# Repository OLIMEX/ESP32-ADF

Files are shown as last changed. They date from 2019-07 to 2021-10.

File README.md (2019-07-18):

# ESP32-ADF
ESP32 Audio Development Framework development board

[ESP32-ADF product page](https://www.olimex.com/Products/IoT/ESP32/ESP32-ADF/)

# ESP32-ADF board has these features:
- ESP32-WROVER-B module with 8MB PSRAM, 4MB Flash
- Stereo codec and Audio Amplifier 2x3W
- Stereo Microphones
- Audio out 3.5mm jack
- UEXT connector for sensors and LCDs
- Lipo battery charger
- USB connector and programmer
- Four touch buttons, 3 tactile buttons
- power supply Jack for +5V 1A

# License
- Hardware is with CERN OHL v1.2 license
- Software is with GPL3 license
- Documentation is with CC BY-SA 4.0 license

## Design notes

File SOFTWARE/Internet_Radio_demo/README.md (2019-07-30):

# Play HTTP aac Living stream

The demo plays a m3u downloaded from HTTP. 

## Compatibility

ESP32-ADF
https://www.olimex.com/Products/IoT/ESP32/ESP32-ADF/open-source-hardware

## Usage

Prepare the audio board:

- Connect speakers or headphones to the board.

# Get ESP-ADF
```bash
cd ~/
git clone --recursive https://github.com/espressif/esp-adf.git
cd esp-adf
git submodule update --init
export ADF_PATH=~/esp-adf
```

Load the example:
```bash
git clone https://github.com/d3v1c3nv11/internet_radio_demo.git
cd internet_radio_demo
make menuconfig
```
Configure the example:

- Set up the Wi-Fi connection by running `menuconfig` > `Example Configuration` and filling in `WiFi SSID` and `WiFi Password`.

Run the example:

```bash
make flash monitor
```
- The audio board will first connect to the Wi-Fi.
- Then the board will start playing automatically.
```bash
Use Touch buttons:
Volume: Vol- Vol+
Next station: <Play>
Presset station: <Set>
```

Note: Patch is required to es8388 driver in esp-adf to enable speakers. From project directory run
```bash
patch $ADF_PATH/components/audio_hal/driver/es8388/es8388.c < es8388_fix_speaker_volume.patch 
```
Graphical part of project is based on loboris/ESP32_TFT_library https://github.com/loboris/ESP32_TFT_library

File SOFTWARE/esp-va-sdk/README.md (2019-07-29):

## Overview

The ESP-Voice-Assistant SDK provides an implementation of Amazon's Alexa Voice Service, Google Voice Assistant and Google's conversational interface (aka Dialogflow) for ESP32 microcontroller. This facilitates the developers to evaluate ESP32 based voice assistant/s integrated devices like speakers and other IoT devices. Please refer to [Changelog](CHANGELOG.md) to track release changes and known-issues.

## License
* For LyratD-DSPG board based on DSPG's DBMD5P DSP please read the licensing terms [here](board_support_pkgs/lyratd_dspg/dspg_fw/docs/license.pdf) for the DSP fimrware
* For rest of the ESP-VA-SDK components please refer to the licensing terms [here](LICENSE)

### About SDK

The SDK contains pre-built libraries for Amazon Alexa, Google Voice Assistant (GVA) and Google Dialogflow along with sources of some of the utility components such as audio pipeline and connection manager. Below are the list of some of the features supported for each voice assistant:
* **Amazon Alexa**:
    * Basic conversation
    * Multi-turn conversations
    * Audio Streaming and Playback
    * Audio Book Support: Kindle, Audible
    * Volume control via voice command
    * Seek support for Audible
    * Alarms, Timers, Reminders, Notifications

* **Google Voice Assistant**:
    * Basic conversation
    * Multi-turn conversations
    * Getting weather reports
    * Multiple language support

* **Google Dialogflow**:
    * Basic conversation
    * Multi-turn conversations
    * Configure and control connected devices via voice, e.g "Start the Laundry"
    * Multiple language support

## Supported Hardware

The SDK supports the following hardware platforms:
* [ESP32-LyraT](https://www.espressif.com/en/products/hardware/esp32-lyrat)
* [ESP32-LyraTD-MSC](https://www.espressif.com/en/products/hardware/esp32-lyratd-msc)
* [Olimex ESP32-ADF](https://www.olimex.com/Products/IoT/ESP32/ESP32-ADF/open-source-hardware)

The following list of acoustic front-ends is also supported. Please contact Espressif to enable acccess to these solutions.
* DSPG DBMD5P
* Intel s1000
* Synaptics CX20921

## Getting started

* Follow the `README-Getting-Started.md` to clone the required repositories and to compile and flash the firmware.
* When flashing the SDK for the first time, it is recommended to do `make erase_flash` to wipe out entire flash and start out fresh.
* Go through `README-<voice_assistant>.md` in their respective directories to know how to provision the device and to get authentication tokens from the respective authorization server and flash them onto the device.
* If you are updating from previous release, please check the `Upgrading from Previous Release` section from `README-Getting-Started.md` to know about any specific actions that needs to be taken while upgrading.

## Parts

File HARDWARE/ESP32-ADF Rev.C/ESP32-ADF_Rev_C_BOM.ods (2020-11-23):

Designation | Quantity | Designator | Package
SMD РЕЗ 0603 1.1 K 1% | 1 | R20 | R_0603_5MIL_DWS
SMD КОНД 0603 100 NF Y5V 50VDC 20% | 2 | C13, C24 | C_0603_5MIL_DWS
100nF/50V/20%/Y5V | 3 | C37,C38, C34 | C_0402_5MIL_DWS
SMD РЕЗ 0402 10 K 5% | 8 | R3,R22,R23,R30,R31,R32,R44,R45 | R_0402_5MIL_DWS
SMD КОНД 0603 10 UF 6.3V | 8 | C8,C9,C10,C11,C12,C18,C25,C26 | C_0603_5MIL_DWS
SMD РЕЗ 0402 1 K 5% | 8 | R8,R5,R7,R28,R29,R24,R41,R42 | R_0402_5MIL_DWS
1N5819S4(SOD-123) | 1 | D5 | SOD-123_1C-2A_KA
1N5822/SS34/SMA | 2 | D4,D6 | SMA-KA
SMD КОНД 0603 1 UF 10V X5R | 5 | C19,C20,C27,C28,C29 | C_0603_5MIL_DWS
SMD РЕЗ 0402 2.2 K 5% | 8 | R4,R13,R15,R18,R21,R26,R27,R43 | R_0402_5MIL_DWS
2.2uH/1.5A/DCR<0.1R/CD32 | 1 | L2 | CD32
SMD КОНД 0402 270 PF 50V C0G | 4 | C30,C32,C35,C36 | C_0402_5MIL_DWS
SMD РЕЗ 0402 220 OHM 5% | 7 | R1,R6,R14,R33,R35,R37,R40 | R_0402_5MIL_DWS
SMD РЕЗ 0402 22 OHM 5% | 1 | R11 | R_0402_5MIL_DWS
22uF/6.3V/20%/X5R/C0603 | 4 | C5,C6,C7,C23 | C_0603_5MIL_DWS
SMD РЕЗ 0402 27 K 5% | 1 | R25 | R_0402_5MIL_DWS
27pF/50V/5%/C0G | 2 | C21,C22 | C_0603_5MIL_DWS
SMD РЕЗ 0402 4.7 OHM 1% | 1 | R16 | R_0402_5MIL_DWS
4.99k/1%/R0603 | 1 | R19 | R_0603_5MIL_DWS
SMD КОНД 0805 47 UF 6.3V 20% | 11 | C1,C2,C3,C4,C14,C15,C16,C17,C31,C33,C39 | C_0805_5MIL_DWS
SMD РЕЗ 0402 510 OHM 5% | 4 | R34,R36,R38,R39 | R_0402_5MIL_DWS
AP1231-33 | 1 | U1 | SOT-23-5
BAT54C(SOT23-3) | 1 | U10 | SOT23
BC817-40(SOT23) | 2 | Q4,Q5 | SOT23
SMD СЪЕДИНИТЕЛ B-V-10-LF (GBH254SMT-10) | 1 | UEXT1 | GBH-254-SMT-10_Smaller
BL4054B-42TPRN(SOT23-5) | 1 | U4 | SOT-23-5
CH340T(SSOP20W) | 1 | U5 | SSOP-20W
DTC114YKA | 1 | Q1 | SOT23
DW02R | 3 | BAT1,LSPK1,RSPK1 | LIPO_BAT-CON2DW02R
ES8388(QFN28) | 1 | U6 | QFN28_EP(29)_4.076x4.076x0.9mm_Pitch_0.45mm
ESP32-WROVER-4MB | 1 | U3 | ESP32-WROVER_MODULE_
FB0805/600R/2A | 5 | FB1,FB2,FB3,FB4, L1 | L_0805_5MIL_DWS
LED/GREEN/0603 | 1 | COMPLETE2 | LED_0603_KA
LED/RED/0603 | 1 | PWRLED1 | LED_0603_KA
LED/YELLOW/0603 | 1 | CHARGING1 | LED_0603_KA
microphone10mm | 2 | MIC1,MIC2 | MIC
MISB-SWMM-5B-LF(USB_MICRO) | 1 | USB-UART1 | USB-MICRO_MISB-SWMM-5B_LF
СМД ИС PAM8003 | 1 | U7 | SO-16
PJ-W47S-05D2-LF_V2 | 1 | AUDIO_JACK_5PIN1 | PJ-W47S-05D2-LF_5PIN_V2
PWRJ-2mm(YDJ-1134) | 1 | PWR1 | PWRJ-2mm(YDJ-1136)
SMD РЕЗ. КВАРЦ 3.2 х 2.5 мм 12 MHz 10ppm 20pF | 1 | Y1 | TSX-3.2x2.5mm_GND(3)
RA1206_(4x0603)_4B8_22R | 1 | RM1 | RA1206_(4X0603)_4B8_mine_1.1
RPM7236-H8 | 1 | U8 | RPM7236-H8
SMBJ6.0A(DO-214AA) | 1 | D2 | DO214AA_1(K)-2(A)
SY8089AAAC(SOT23-5) | 1 | U2 | SOT-23-5
T1107A(6x3,8x2,5MM) | 3 | RST1,BUT1,BUT2 | T1107A(6x3,8x2,5MM)
WPM2015-3/TR | 2 | FET1,FET2 | SOT23
SPEAKER S3W402 (3W 4OHM) | 2
BATTERY CABLE | 2

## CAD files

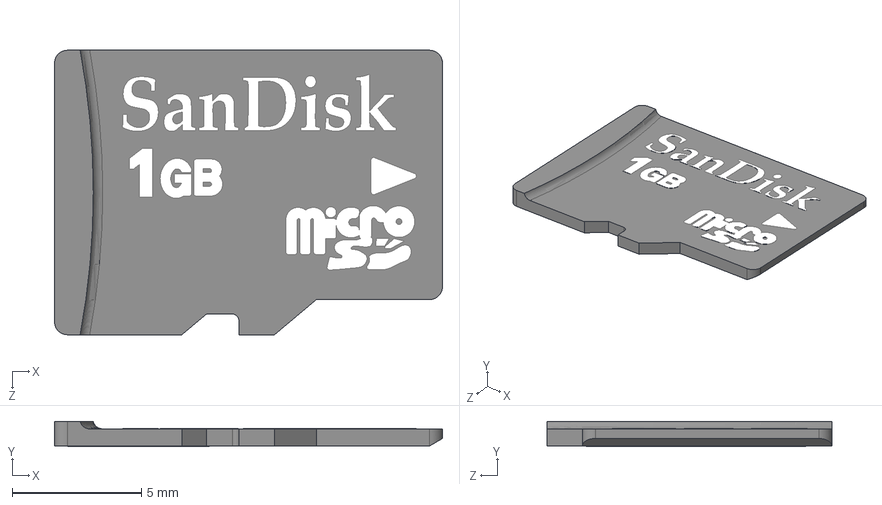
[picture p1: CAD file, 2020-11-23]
HARDWARE/ESP32-ADF Rev.C/3d/Micro_SD_card.step
15.0 x 0.975 x 11.0 mm

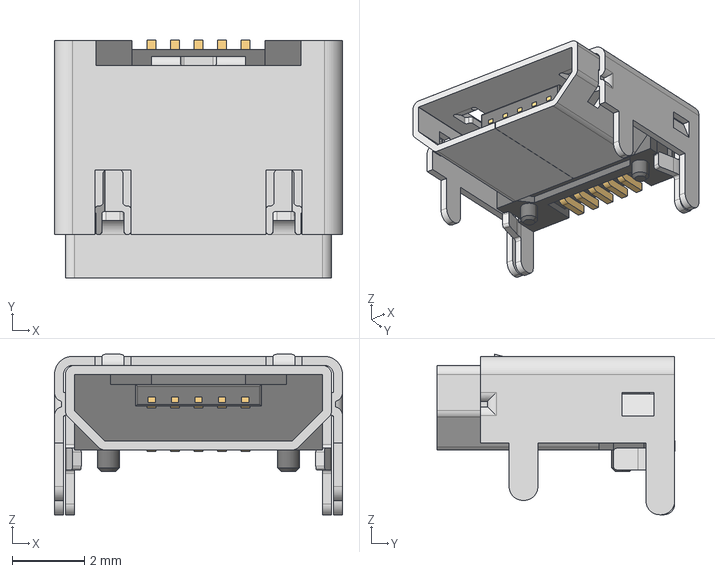
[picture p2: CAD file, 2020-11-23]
HARDWARE/ESP32-ADF Rev.C/3d/usb_micro_4p.stp
8.00 x 6.60 x 4.46 mm

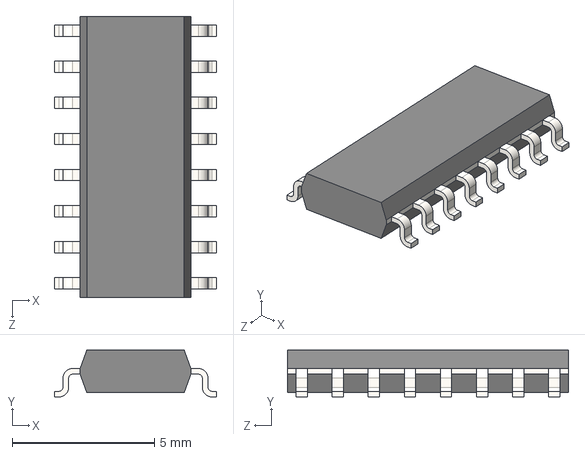
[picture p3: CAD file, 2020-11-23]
HARDWARE/ESP32-ADF Rev.C/3d/SL16.step
5.70 x 1.65 x 9.90 mm

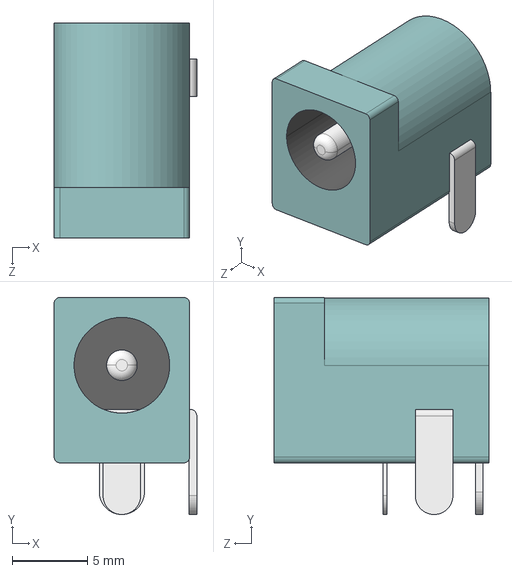
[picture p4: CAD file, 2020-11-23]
HARDWARE/ESP32-ADF Rev.C/3d/User_Library-RAPC722_Power_Jack.step
9.47 x 14.4 x 14.2 mm

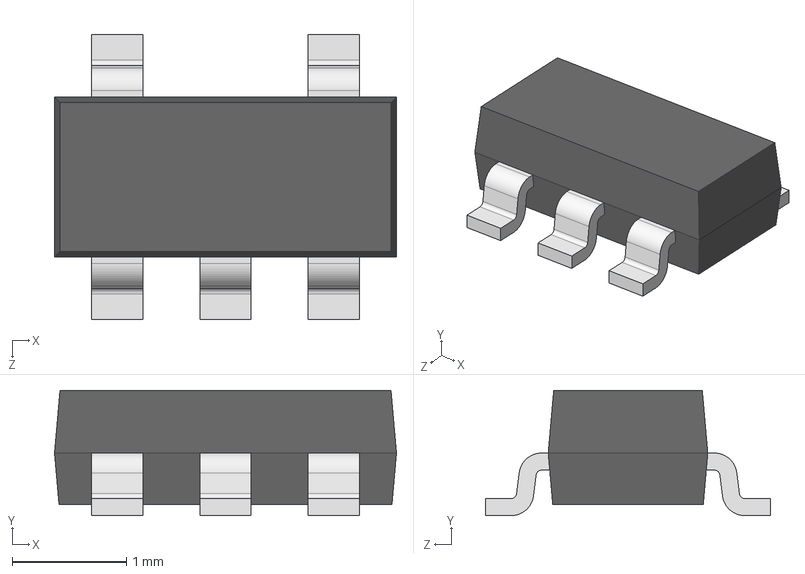
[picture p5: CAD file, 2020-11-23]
HARDWARE/ESP32-ADF Rev.C/3d/SOT-23-5.step
3.00 x 1.10 x 2.50 mm

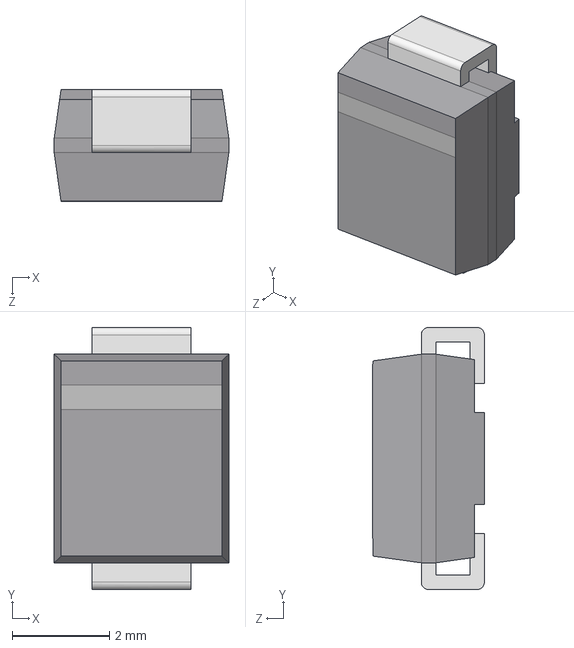
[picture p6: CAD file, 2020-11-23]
HARDWARE/ESP32-ADF Rev.C/3d/DO-214AA_SMB.step
3.60 x 5.40 x 2.30 mm

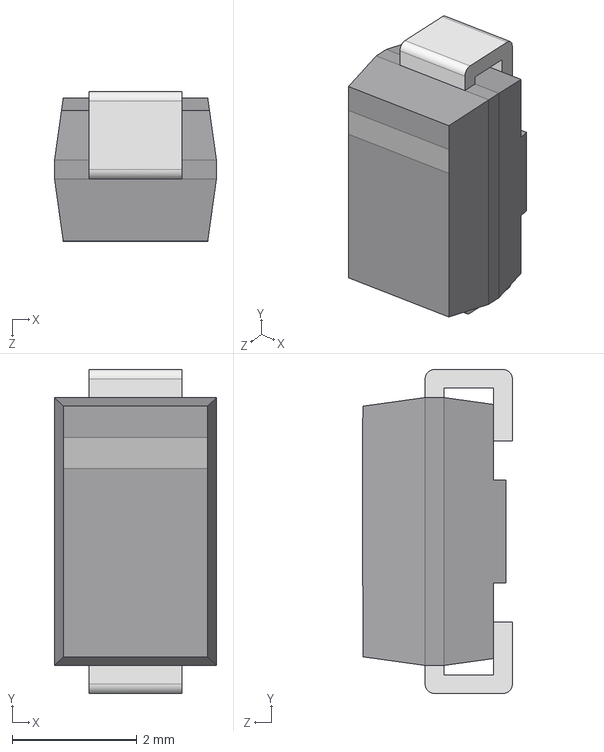
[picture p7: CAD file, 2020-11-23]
HARDWARE/ESP32-ADF Rev.C/3d/DO-214AC_SMA.step
2.60 x 5.20 x 2.40 mm

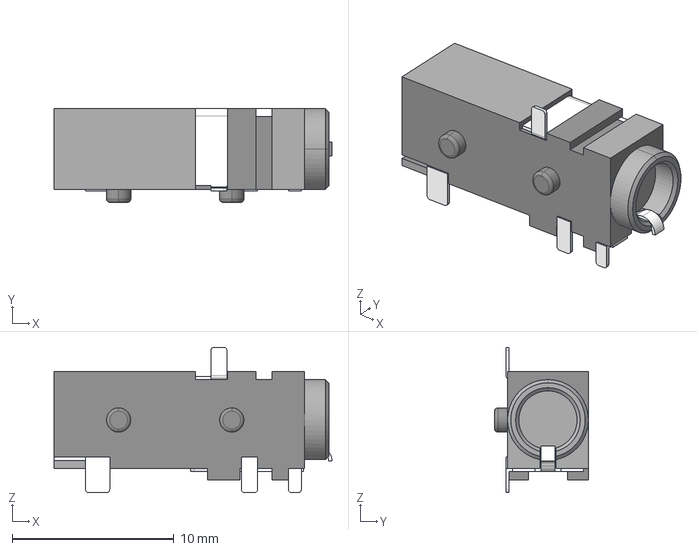
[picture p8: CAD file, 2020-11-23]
HARDWARE/ESP32-ADF Rev.C/3d/sj-43514-smt-tr.stp
17.2 x 5.80 x 9.00 mm

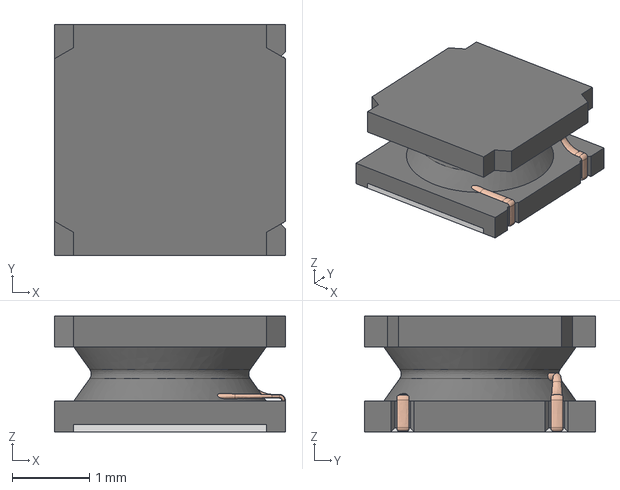
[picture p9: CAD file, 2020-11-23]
HARDWARE/ESP32-ADF Rev.C/3d/L-CD32_shielded.step
3.00 x 3.00 x 1.50 mm

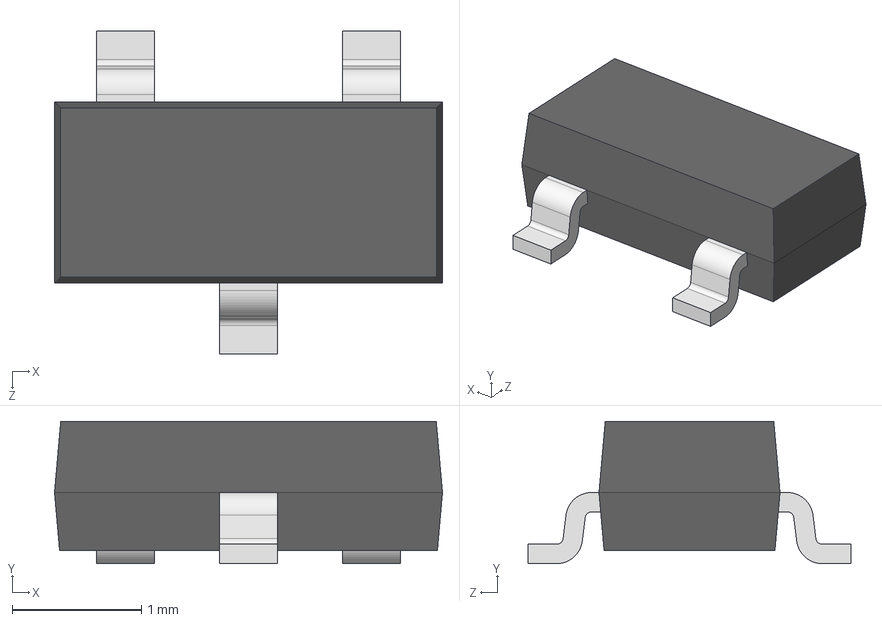
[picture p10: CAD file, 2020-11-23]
HARDWARE/ESP32-ADF Rev.C/3d/SOT-23.step
3.00 x 1.10 x 2.50 mm

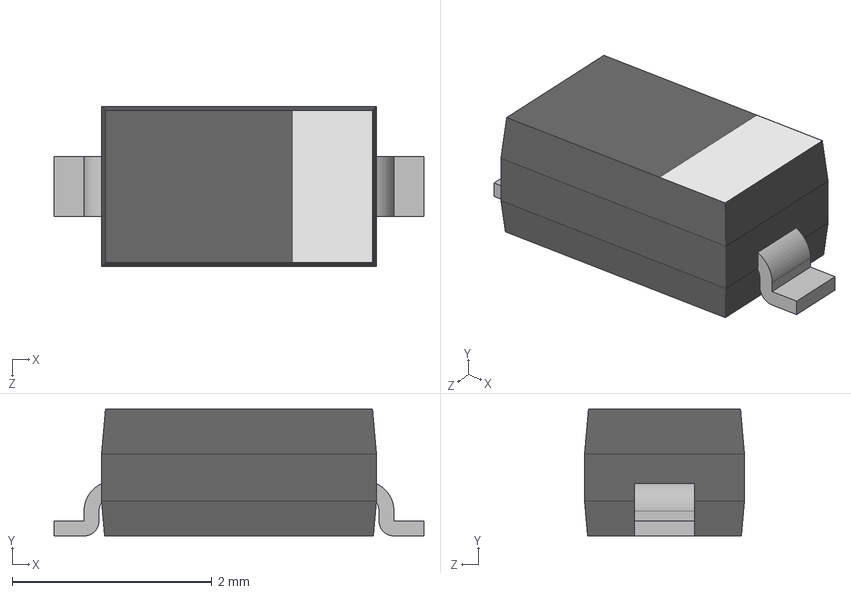
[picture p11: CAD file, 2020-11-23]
HARDWARE/ESP32-ADF Rev.C/3d/SOD123.step
3.70 x 1.27 x 1.60 mm

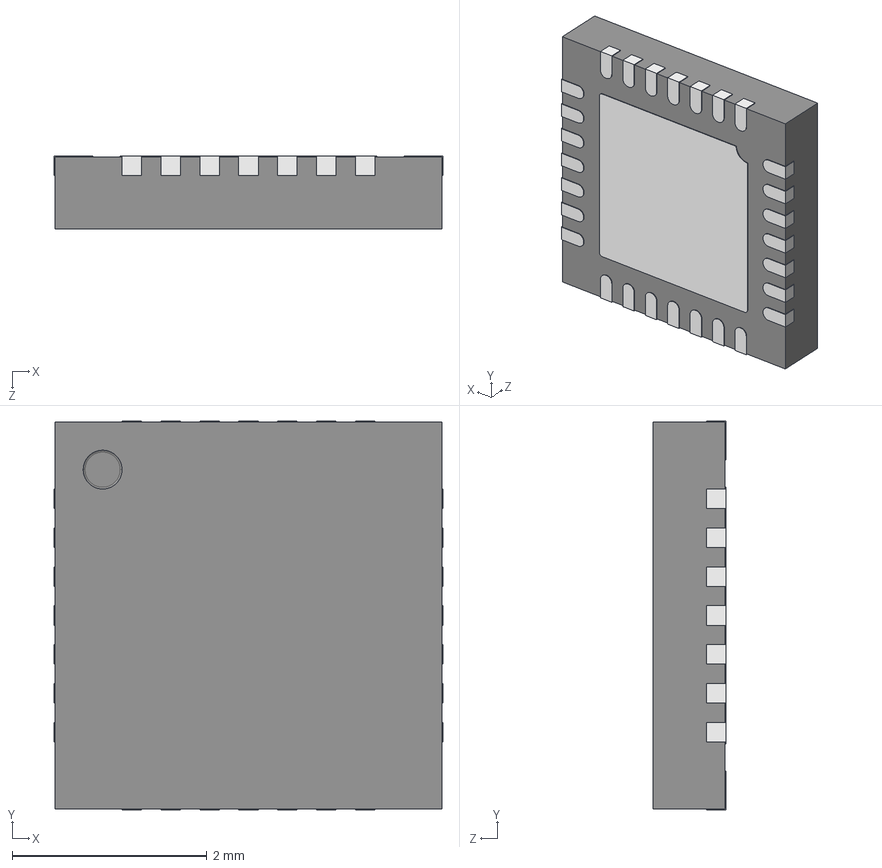
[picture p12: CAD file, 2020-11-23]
HARDWARE/ESP32-ADF Rev.C/3d/QFN28-0_4.STEP
4.00 x 4.00 x 0.75 mm
User Library-QFN28-0_4_Free-Models
User Library-QFN28-0_4_Free-Models016
User Library-QFN28-0_4_Fillet
User Library-QFN28-0_4_Free-Models026
User Library-QFN28-0_4_Free-Models027
User Library-QFN28-0_4_Free-Models028
User Library-QFN28-0_4_Free-Models009
User Library-QFN28-0_4_Free-Models008
User Library-QFN28-0_4_Free-Models007
User Library-QFN28-0_4_Free-Models022
User Library-QFN28-0_4_Free-Models023
User Library-QFN28-0_4_Free-Models001
User Library-QFN28-0_4_Free-Models003
User Library-QFN28-0_4_Free-Models002
User Library-QFN28-0_4_Free-Models024
User Library-QFN28-0_4_Free-Models025
User Library-QFN28-0_4_Free-Models014
User Library-QFN28-0_4_Free-Models013
User Library-QFN28-0_4_Free-Models015
User Library-QFN28-0_4_Free-Models017
User Library-QFN28-0_4_Free-Models018
User Library-QFN28-0_4_Free-Models020
User Library-QFN28-0_4_Free-Models021
User Library-QFN28-0_4_Free-Models019
User Library-QFN28-0_4_Free-Models005
User Library-QFN28-0_4_Free-Models004
User Library-QFN28-0_4_Free-Models006
User Library-QFN28-0_4_Free-Models012
User Library-QFN28-0_4_Free-Models011
User Library-QFN28-0_4_Free-Models010

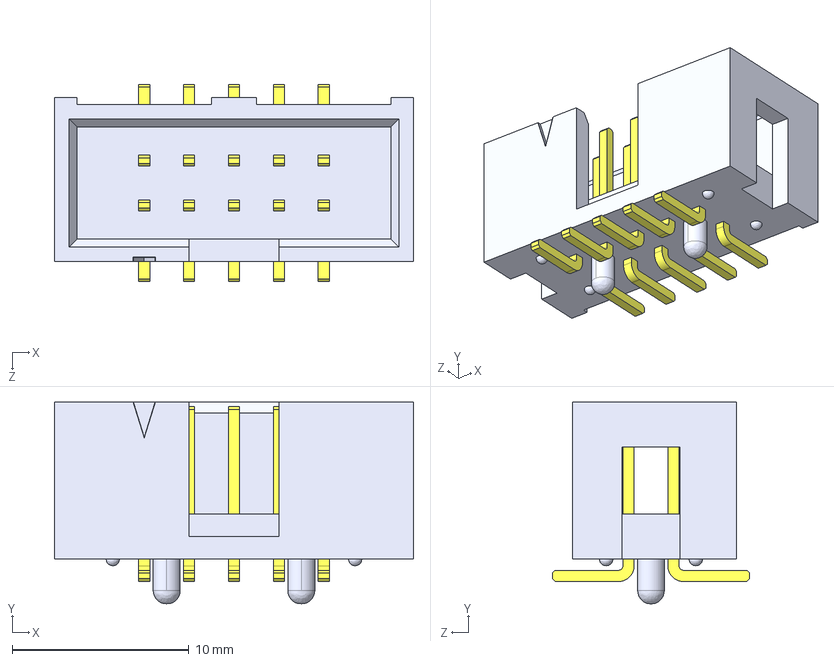
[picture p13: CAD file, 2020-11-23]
HARDWARE/ESP32-ADF Rev.C/3d/UEXT-SMD.STEP
20.3 x 11.4 x 11.2 mm
User Library-HTST-105-01-F-DV-A__HTST-105-01-DV-A_header
User Library-HTST-105-01-F-DV-A__HTST-First_Position_Indicator
User Library-HTST-105-01-F-DV-A__T-1S6-05-01-DV_

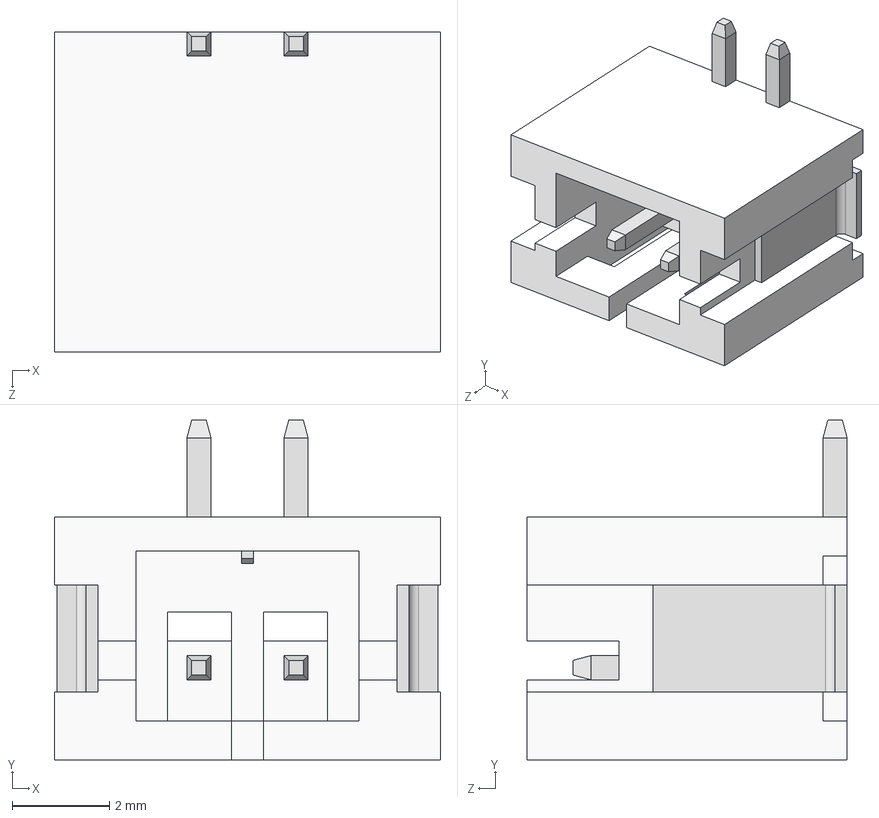
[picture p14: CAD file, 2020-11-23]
HARDWARE/ESP32-ADF Rev.C/3d/JST_B2B-PH-SM4-TB(DW02R).step
7.95 x 7.00 x 6.60 mm

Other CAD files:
HARDWARE/ESP32-ADF Rev.C/3d/ESP32-WROVER-I-56544.STEP
HARDWARE/ESP32-ADF Rev.C/3d/T1107A.STEP
HARDWARE/ESP32-ADF Rev.C/3d/QSG5032.step
HARDWARE/ESP32-ADF Rev.C/3d/rubber_feet.step
HARDWARE/ESP32-ADF Rev.B/3d/DO-214AA_SMB.step
HARDWARE/ESP32-ADF Rev.B/3d/DO-214AC_SMA.step
HARDWARE/ESP32-ADF Rev.B/3d/ESP32-WROVER-I-56544.STEP
HARDWARE/ESP32-ADF Rev.B/3d/JST_B2B-PH-SM4-TB(DW02R).step
HARDWARE/ESP32-ADF Rev.B/3d/L-CD32_shielded.step
HARDWARE/ESP32-ADF Rev.B/3d/QFN28-0_4.STEP
HARDWARE/ESP32-ADF Rev.B/3d/QSG5032.step
HARDWARE/ESP32-ADF Rev.B/3d/SL16.step
HARDWARE/ESP32-ADF Rev.B/3d/SOD123.step
HARDWARE/ESP32-ADF Rev.B/3d/SOT-23-5.step
HARDWARE/ESP32-ADF Rev.B/3d/SOT-23.step
HARDWARE/ESP32-ADF Rev.B/3d/T1107A.STEP
HARDWARE/ESP32-ADF Rev.B/3d/UEXT-SMD.STEP
HARDWARE/ESP32-ADF Rev.B/3d/User_Library-Parallax-IR.step
HARDWARE/ESP32-ADF Rev.B/3d/User_Library-RAPC722_Power_Jack.step
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

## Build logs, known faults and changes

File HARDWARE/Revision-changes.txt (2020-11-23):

Hardware revision changes

Revision C

1. Headphone detect is no longer wired ot the ESP32 module, operates directly the PA enable.
2. Added jumper SJ1 - by default open; if you close it it will disable PA. For projects without speakers.
3. Added SD card. 
4. Kept maximum compatiblity with lyRa 4.3, only board.h changes required.
5. SPI of UEXT connected with hspi to esp32 at pins 12, 13, 14, 15.
6. Changed some wires of UART1, IRRX.

Revision B

Module ESP32-WROOM changed with ESP32-WROVER

Revision A - initial release

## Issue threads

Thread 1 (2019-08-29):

Compile issue

eeskbala, 2019-08-29:
We are having issues compiling the current HEAD on the master

esp-idf/components/asio/asio/asio/src/asio.cpp:11:
/home/skb/.espressif/tools/xtensa-esp32-elf/esp32-2019r1-8.2.0/xtensa-esp32-elf/xtensa-esp32-elf/sys-include/stdlib.h:155:44: error: expected initializer before '__result_use_check'
 void *reallocarray(void *, size_t, size_t) __result_use_check __alloc_size(2)

DanKoloff, 2019-08-30:
Which of the two examples are you trying to compile? Can you also give us more details about your software setup?

Closed 2021-10-04.

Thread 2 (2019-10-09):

MOD-SD_MMC compatiblity

timotoots, 2019-10-09:
Would you mind explaining or making a demo how to connect your SD Card UEXT reader to ESP32-ADF and play files from the card? The demos of ESP-ADF are not working out of the box.

DanKoloff, 2019-10-30:
These two should work together just fine.

Navigate to the the IDF component in the ADF framework. Get to the SD card example and read the info: https://github.com/espressif/esp-idf/tree/4aa1058e8a8f7f3fb17d9ac1158227ad161f2996/examples/storage/sd_card

You only need to edit the beginning of the code to the proper pins (refer to the schematic of the board that shows the UEXT for the proper pins in case I made a mistake):

#ifdef USE_SPI_MODE
// Pin mapping when using SPI mode.
// With this mapping, SD card can be used both in SPI and 1-line SD mode.
// Note that a pull-up on CS line is required in SD mode.
#define PIN_NUM_MISO 15
#define PIN_NUM_MOSI 2
#define PIN_NUM_CLK  14
#define PIN_NUM_CS   21
#endif //USE_SPI_MODE

IMPORTANT: This applies only for revision B of the ESP32-ADF board. Future revisions might have it different.

Closed 2020-06-03.

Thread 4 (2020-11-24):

White screen - Rev-C compatibility?

jhancharler, 2020-11-24:
Is the SIP VoIP example compatible with the Rev C board?

I am using an ESP32-ADF rev C with a MOD-LCD2.8RTP board. When flashing the screen remains white and no particular audio plays on the audio.

DanKoloff, 2020-11-24:
Yes, it was updated two months ago. Did you try different audio type? Did you try different options in make menuconfig?

Check this commit that added revision C specifics:

https://github.com/OLIMEX/sip_phone_example/commit/5fc350a07d17ebc43190c44a35fc35ec5114744d

jhancharler, 2020-11-27:
I did try different audio types. The one thing I haven't done yet is set up the SIP URI information. Is that necessary before the screen is booted?

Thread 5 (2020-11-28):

error: 'TOUCH_PAD_NUM9' undeclared

modularev, 2020-11-28:
Replacing the `#define BUTTON_SET_ID TOUCH_PAD_NUM9` with `#define BUTTON_SET_ID 9` works as expected. Is there an additional `#include` needed?

modularev, 2020-11-28:
adding `#include "hal/touch_sensor_types.h"` inside `board_pins_config.c`fixes the issue.

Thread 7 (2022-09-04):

Line in Input, how?

mkoenings, 2022-09-04:
Hello,
thanks for this great product. It works really well. However, I need the line-in input, in order to create an application for musical intruments. There is no pin available for this, correct ?  I am willing to sacrifice the microphones ( de-solder) if necessary. What else needs to be done ?  Which registers have to be changed ? Thanks a lot, Michael

DanKoloff, 2022-09-05:
I think it is possible but I can't give you exact step-by-step details since we haven't done it ourselves and also there are multiple options. It would require some hardware changes for sure. Look at the schematic. You can either use the unused LIN2 or RIN2 or modify the already used LIN1 and RIN1. If you want to use the unused LIN2 or RIN2 are unrouted in our design (meaning you'd need to solder wires directly to ES8388's pins #22 and #21). Maybe if it was me I'd go that path and just solder two wires to the free pins and lead them to breadboard to experiment with them further.

Alternatively if you want to use LIN1 for line input the first thing you would have to remove R27.

ESP32-ADF uses Everest ES8388 so first make sure to take a look at ES8388 datasheet AND its user manual (the manual has some examples and register considerations).

mkoenings, 2022-09-05:
thank you! I will try to use the LIN1,  I dont feel comfortable wiring these tinypins on the chip :-)
I wasnt aware of the user manual, that might be helpful.
Cheers!

Closed 2022-10-20.

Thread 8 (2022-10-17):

Reading battery voltage

jwktje, 2022-10-17:
Is there a way to read the battery voltage and get a rough estimate of the remaining battery percentage?

I tried looking for a voltage divider for this in the schematic but couldn’t find it.

DanKoloff, 2022-10-20:
ESP32-ADF has no battery voltage measuring nor battery presence functionality. You can check how this functionality was enabled in ESP32-POE or ESP32-POE-ISO if you wish to implement such. You can find these here (in the top left section named "Power supply"):

https://github.com/OLIMEX/ESP32-POE/blob/master/HARDWARE/ESP32-PoE-hardware-revision-I/ESP32-PoE_Rev_I.pdf

https://github.com/OLIMEX/ESP32-POE-ISO/blob/master/HARDWARE/ESP32-PoE-ISO-Rev.H/ESP32-PoE-ISO_Rev_H.pdf

jwktje, 2023-06-17:
@DanKoloff I see. It looks like I would need to sacrifice the Mode button as there is no free GPIO for this on the ESP32-ADF. Would you guys consider a revision or alternate version that removes the Mode button in exchange for external battery voltage sensing?

Closed 2022-10-20.

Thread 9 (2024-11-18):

How to use in arduino

philippejadin, 2024-11-18:
Hello,

I just ordered this board which seems perfect for my project. I'd like to use arduino (or even better platformio using arduino core) to program it. My question is :  which board would you recommend to select under the esp32 category in arduino ide? There are a tons of boards mentioned there, including boards from olimex, but unfortunately not this specific one. I guess I could select the generic "WROVER esp32 module", but maybe you have a better idea :)

Thank you!

DanKoloff, 2024-11-19:
We haven't made an entry for ESP32-ADF, so generic it is.

philippejadin, 2024-11-19:
This is fine. I will purpose a pull request with example using Arduino
audio tools if I manage to make it work 🙂

Le mar. 19 nov. 2024, 11:48, DanKoloff ***@***.***> a écrit :

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

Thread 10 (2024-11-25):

Very Low volume from speaker

hmd83, 2024-11-25:
### Environment
- ESP-IDF Version: v5.3
- ADF Version: 2.7

### Steps to Reproduce
1. Initialize audio system
2. Set volume to maximum (99)
3. Play audio
4. Observe very low volume output

### Expected Behavior
Speaker should output audio at high volume when volume is set to 99.

### Additional Information
- PA settings don't affect the volume significantly
- Volume is consistently low across different audio sources
- No error messages are displayed when setting volume

### Questions for Troubleshooting
1. Is this a known issue with ADF 2.7?
2. Are there any specific codec configurations needed for proper volume control?
3. Could this be related to DAC gain settings?

---
**Tags**: esp32, audio, volume-control, esp-adf,OLIMEX

DanKoloff, 2024-11-26:
Just a suggestion to search for similar complaint in Espressif forums or also post there. If it is related to ADF 2.7 probably all similar boards would be affected.

hmd83, 2024-11-26:
# thnaks for your suggestion  but Board.h Configuration Issues with OLIMEX ESP32-ADF @DanKoloff

## Issue Description

I'm experiencing configuration challenges with the OLIMEX ESP32-ADF board while trying to port existing code from an ESP32-Audio-Kit (Ai-Thinker).

The documentation mentions "**Kept maximum compatibility with lyRa 4.3, only board.h changes required**" but provides no clear guidance on the specific changes needed in `board.h` for proper operation.

## Current Situation

- Working with ESP-IDF framework for commercial application
- Same code functions correctly on Ai-Thinker ESP32-Audio-Kit with just I2S and I2C pin reconfigurations
- Looking for more robust hardware solution with OLIMEX
- Need clarification on required `board.h` modifications

## Tags
- esp32
- audio
- volume-control
- esp-adf
- OLIMEX

## Questions

1. What specific changes are required in `board.h` for OLIMEX ESP32-ADF compatibility?
2. Is there documentation detailing the pin mappings and configurations?
3. Are there any reference examples using ESP-IDF framework?

---

DanKoloff, 2024-11-26:
Use the configs from the demos we've published and compare. Like from the dance radio or sip phone examples:

https://github.com/OLIMEX/dance_radio/tree/master/components/audio_board/olimex_esp32_adf_c

https://github.com/OLIMEX/sip_phone_example/tree/master/components/audio_board/olimex_esp32_adf_c

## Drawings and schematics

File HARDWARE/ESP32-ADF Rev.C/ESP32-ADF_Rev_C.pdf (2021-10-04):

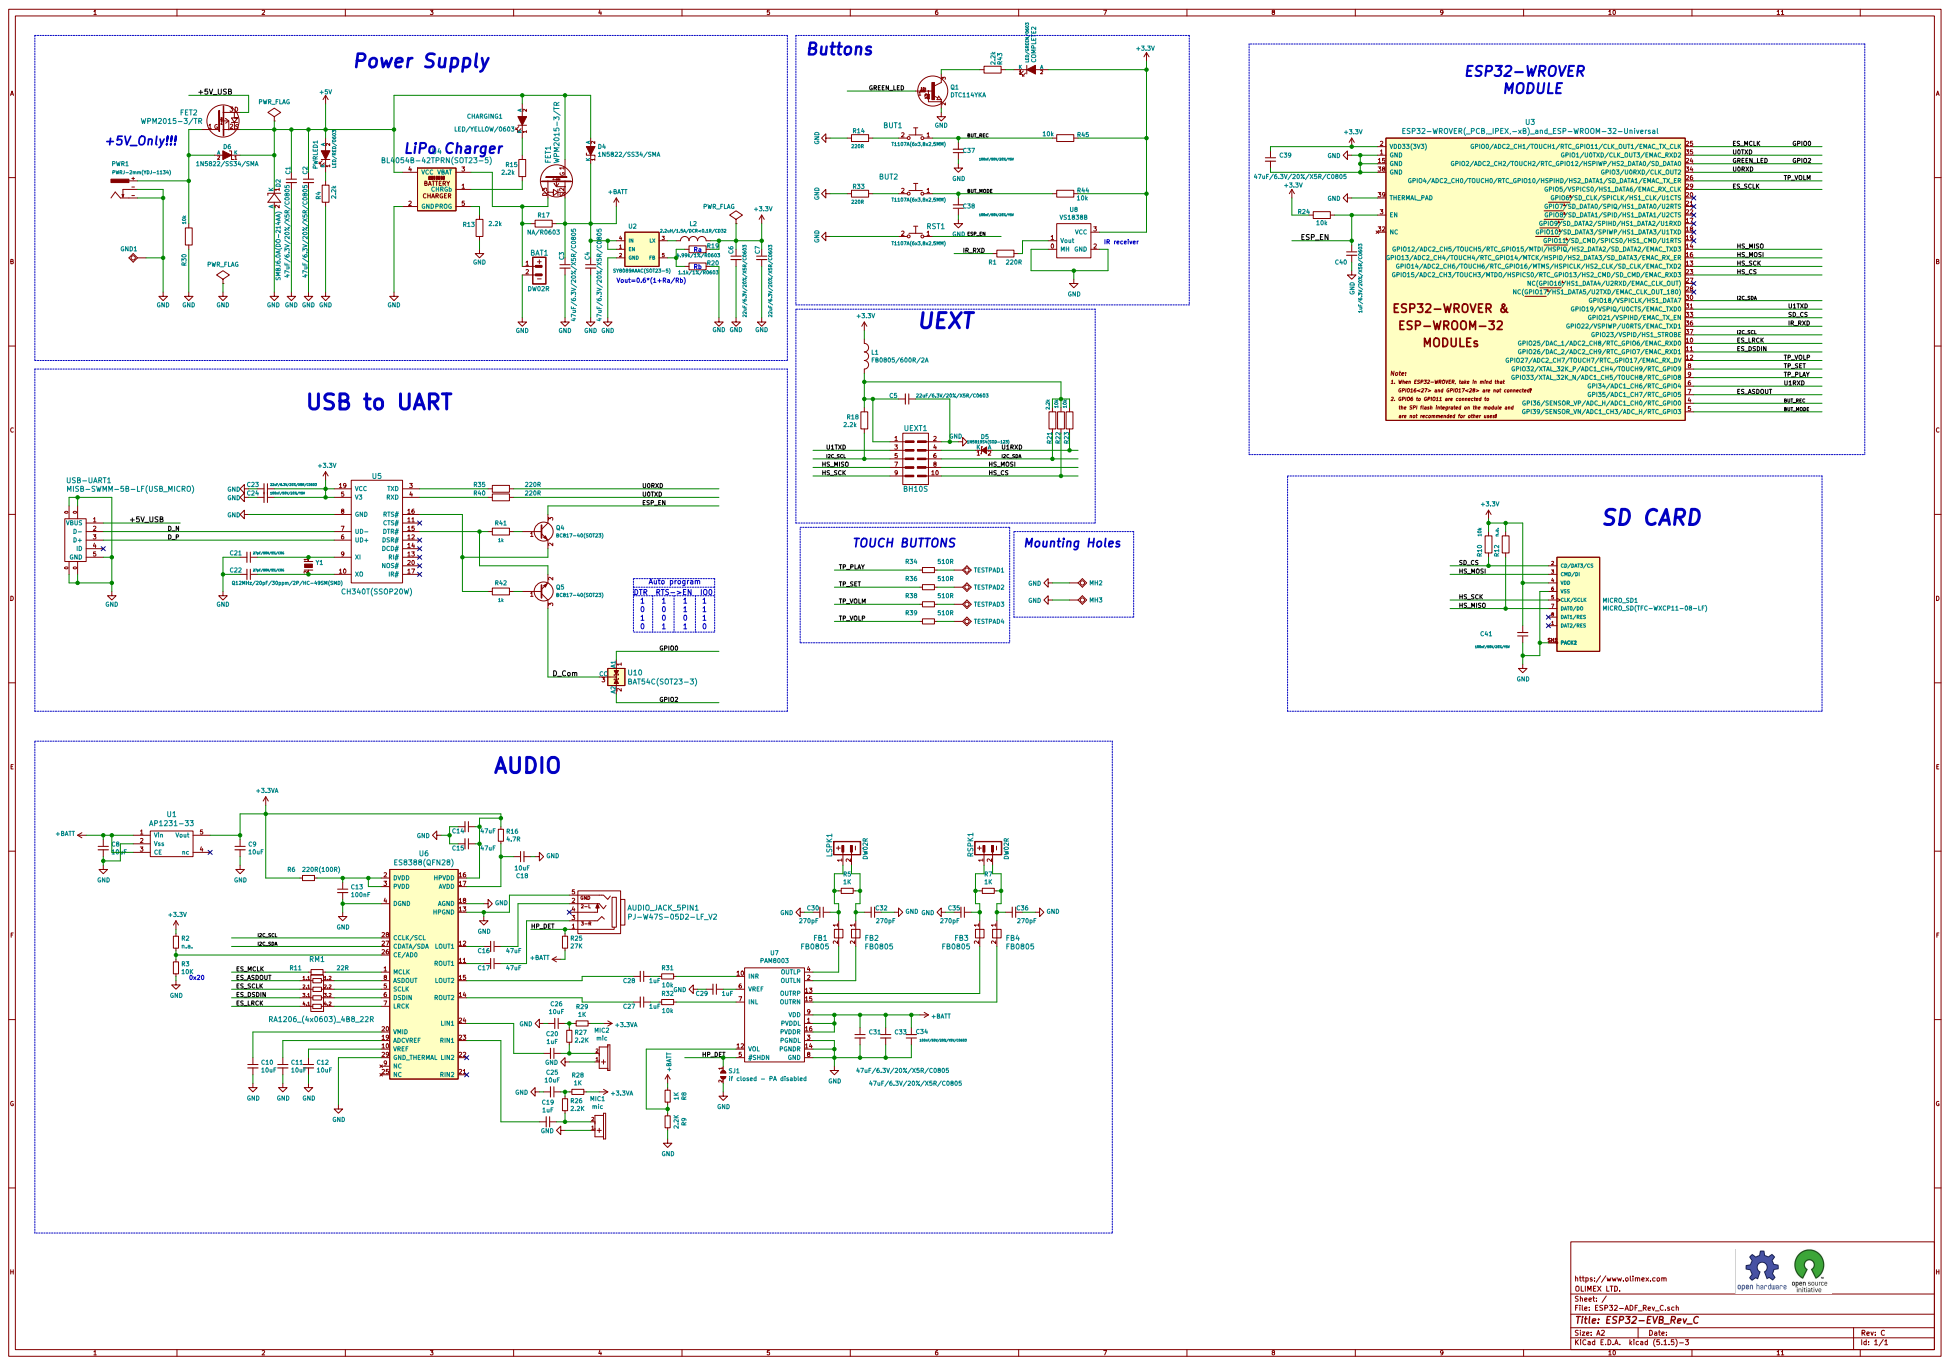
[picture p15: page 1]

the SPI flash integrated on the module and GND
14 GND
37 GND

2.2. 2. 2.2. 2. 2. GPIO6 to GPIO11 are connected to are not recommended for other uses! ESP-WROOM-32

1. 1. 1. When ESP32-WROVER, take in mind that
ESP32-WROVER &

1 2 Y1 Q12MHz/20pF/30ppm/2P/HC-49SM(SMD) C21 27pF/50V/5%/C0G GND GND

GPIO16<27> and GPIO17<28> are not connected! MODULEs

if closed - PA disabled GND

File: ESP32-ADF_Rev_C.sch Sheet: / OLIMEX LTD. https://www.olimex.com

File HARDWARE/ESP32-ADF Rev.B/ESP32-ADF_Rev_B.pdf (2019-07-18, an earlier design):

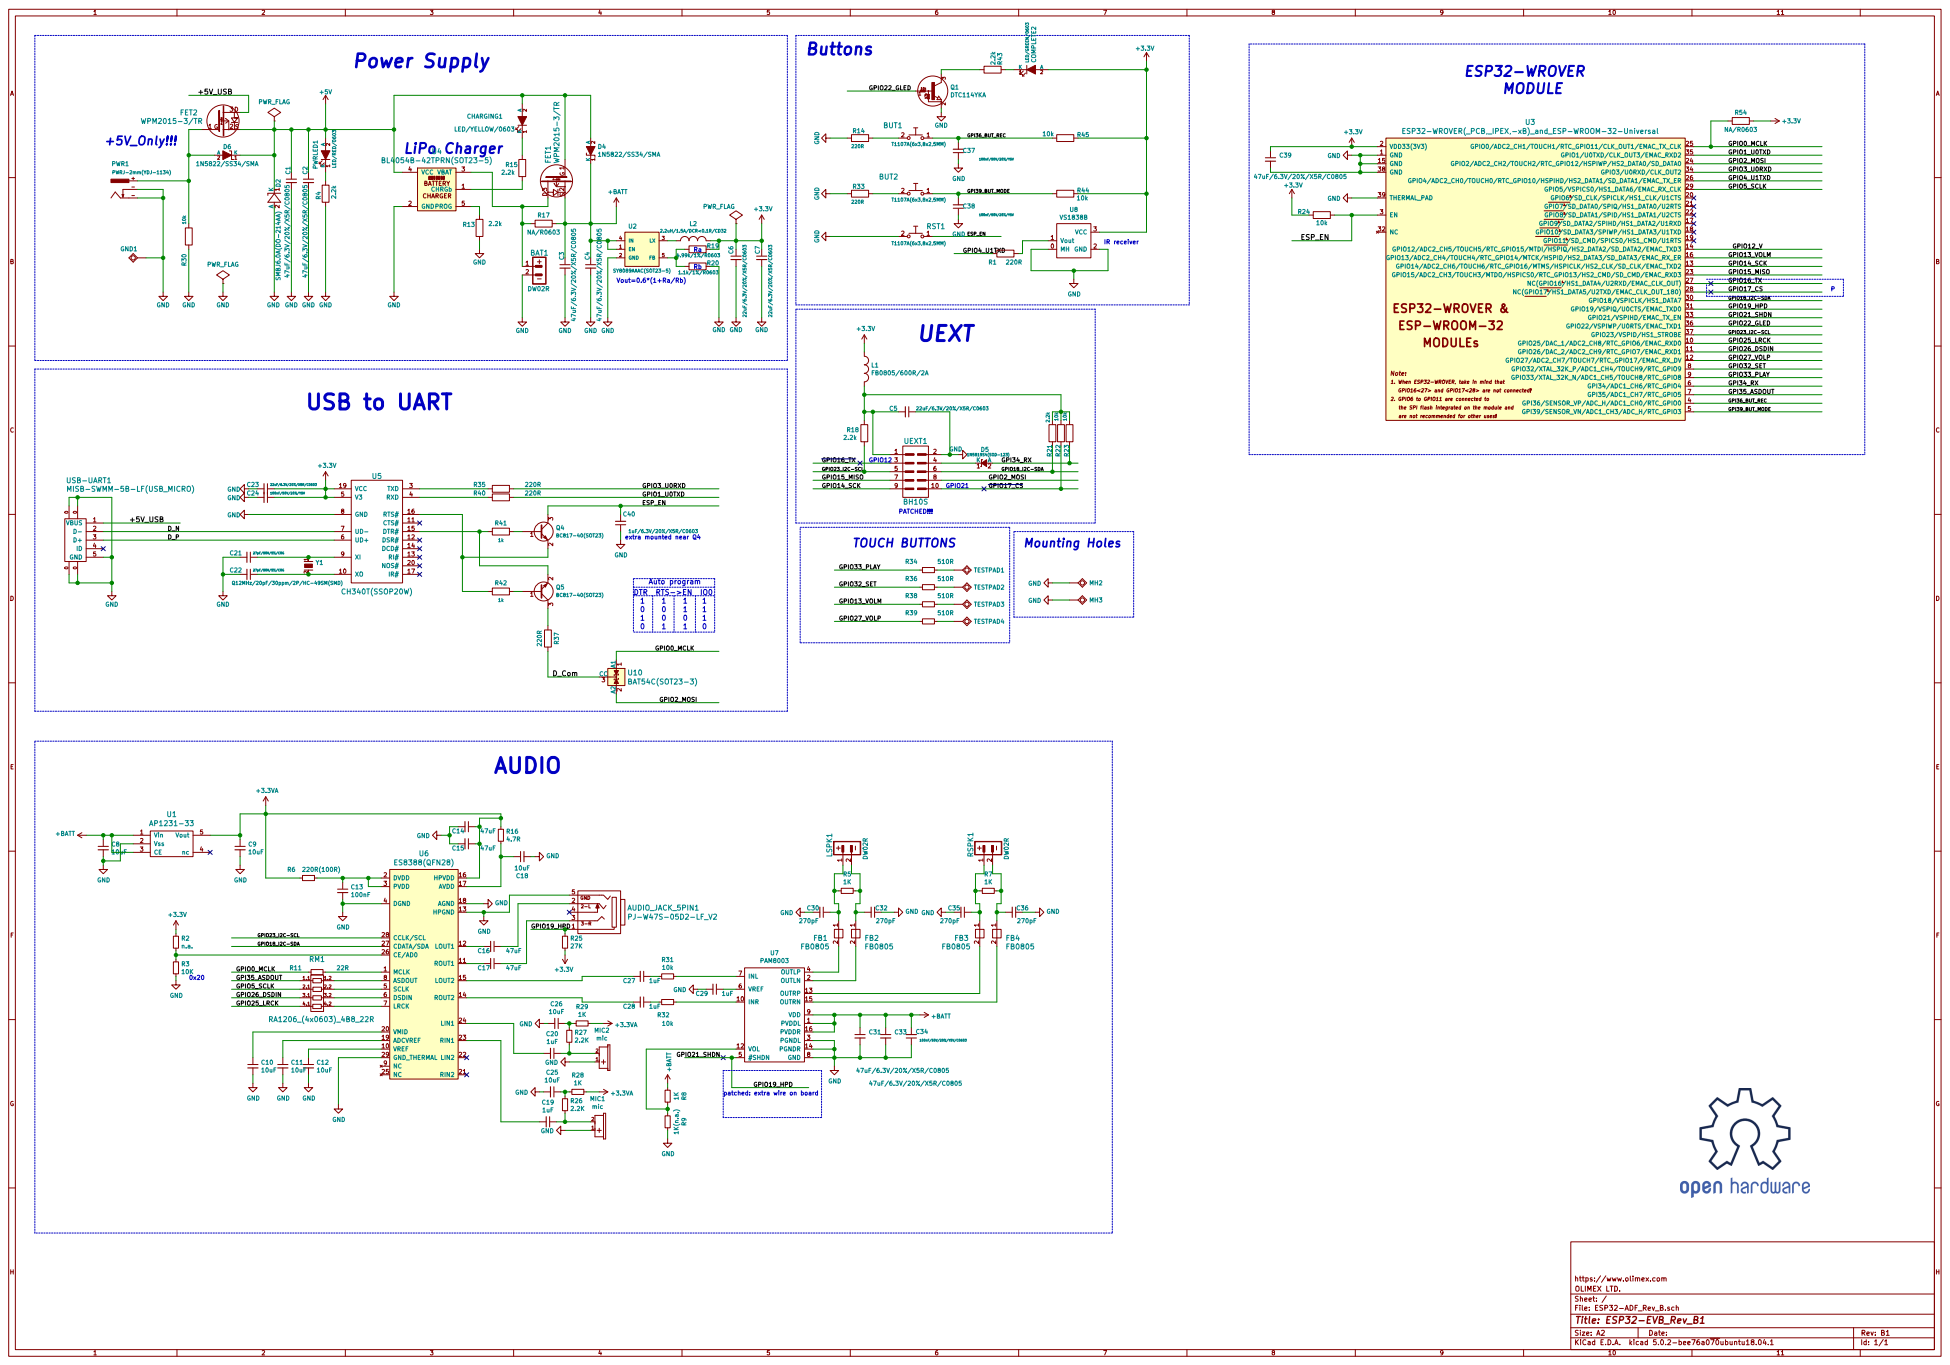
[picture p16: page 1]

9 U3 ESP32-WROVER(_PCB,_IPEX,-xB)_and_ESP-WROOM-32-Universal +BATT 1KR8 R9 1K(n.a.) GND

the SPI flash integrated on the module and GND
14 GND
38 THERMAL_PAD
37 GND

2 PWRLED1 LED/RED/0603 GND GND GND GND GND

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

1. 1. 1. When ESP32-WROVER, take in mind that
ESP32-WROVER &

GPIO16<27> and GPIO17<28> are not connected! MODULEs

+3.3V +5V_USB
MISB-SWMM-5B-LF(USB_MICRO) GND

patched: extra wire on board

File: ESP32-ADF_Rev_B.sch Sheet: / OLIMEX LTD. https://www.olimex.com

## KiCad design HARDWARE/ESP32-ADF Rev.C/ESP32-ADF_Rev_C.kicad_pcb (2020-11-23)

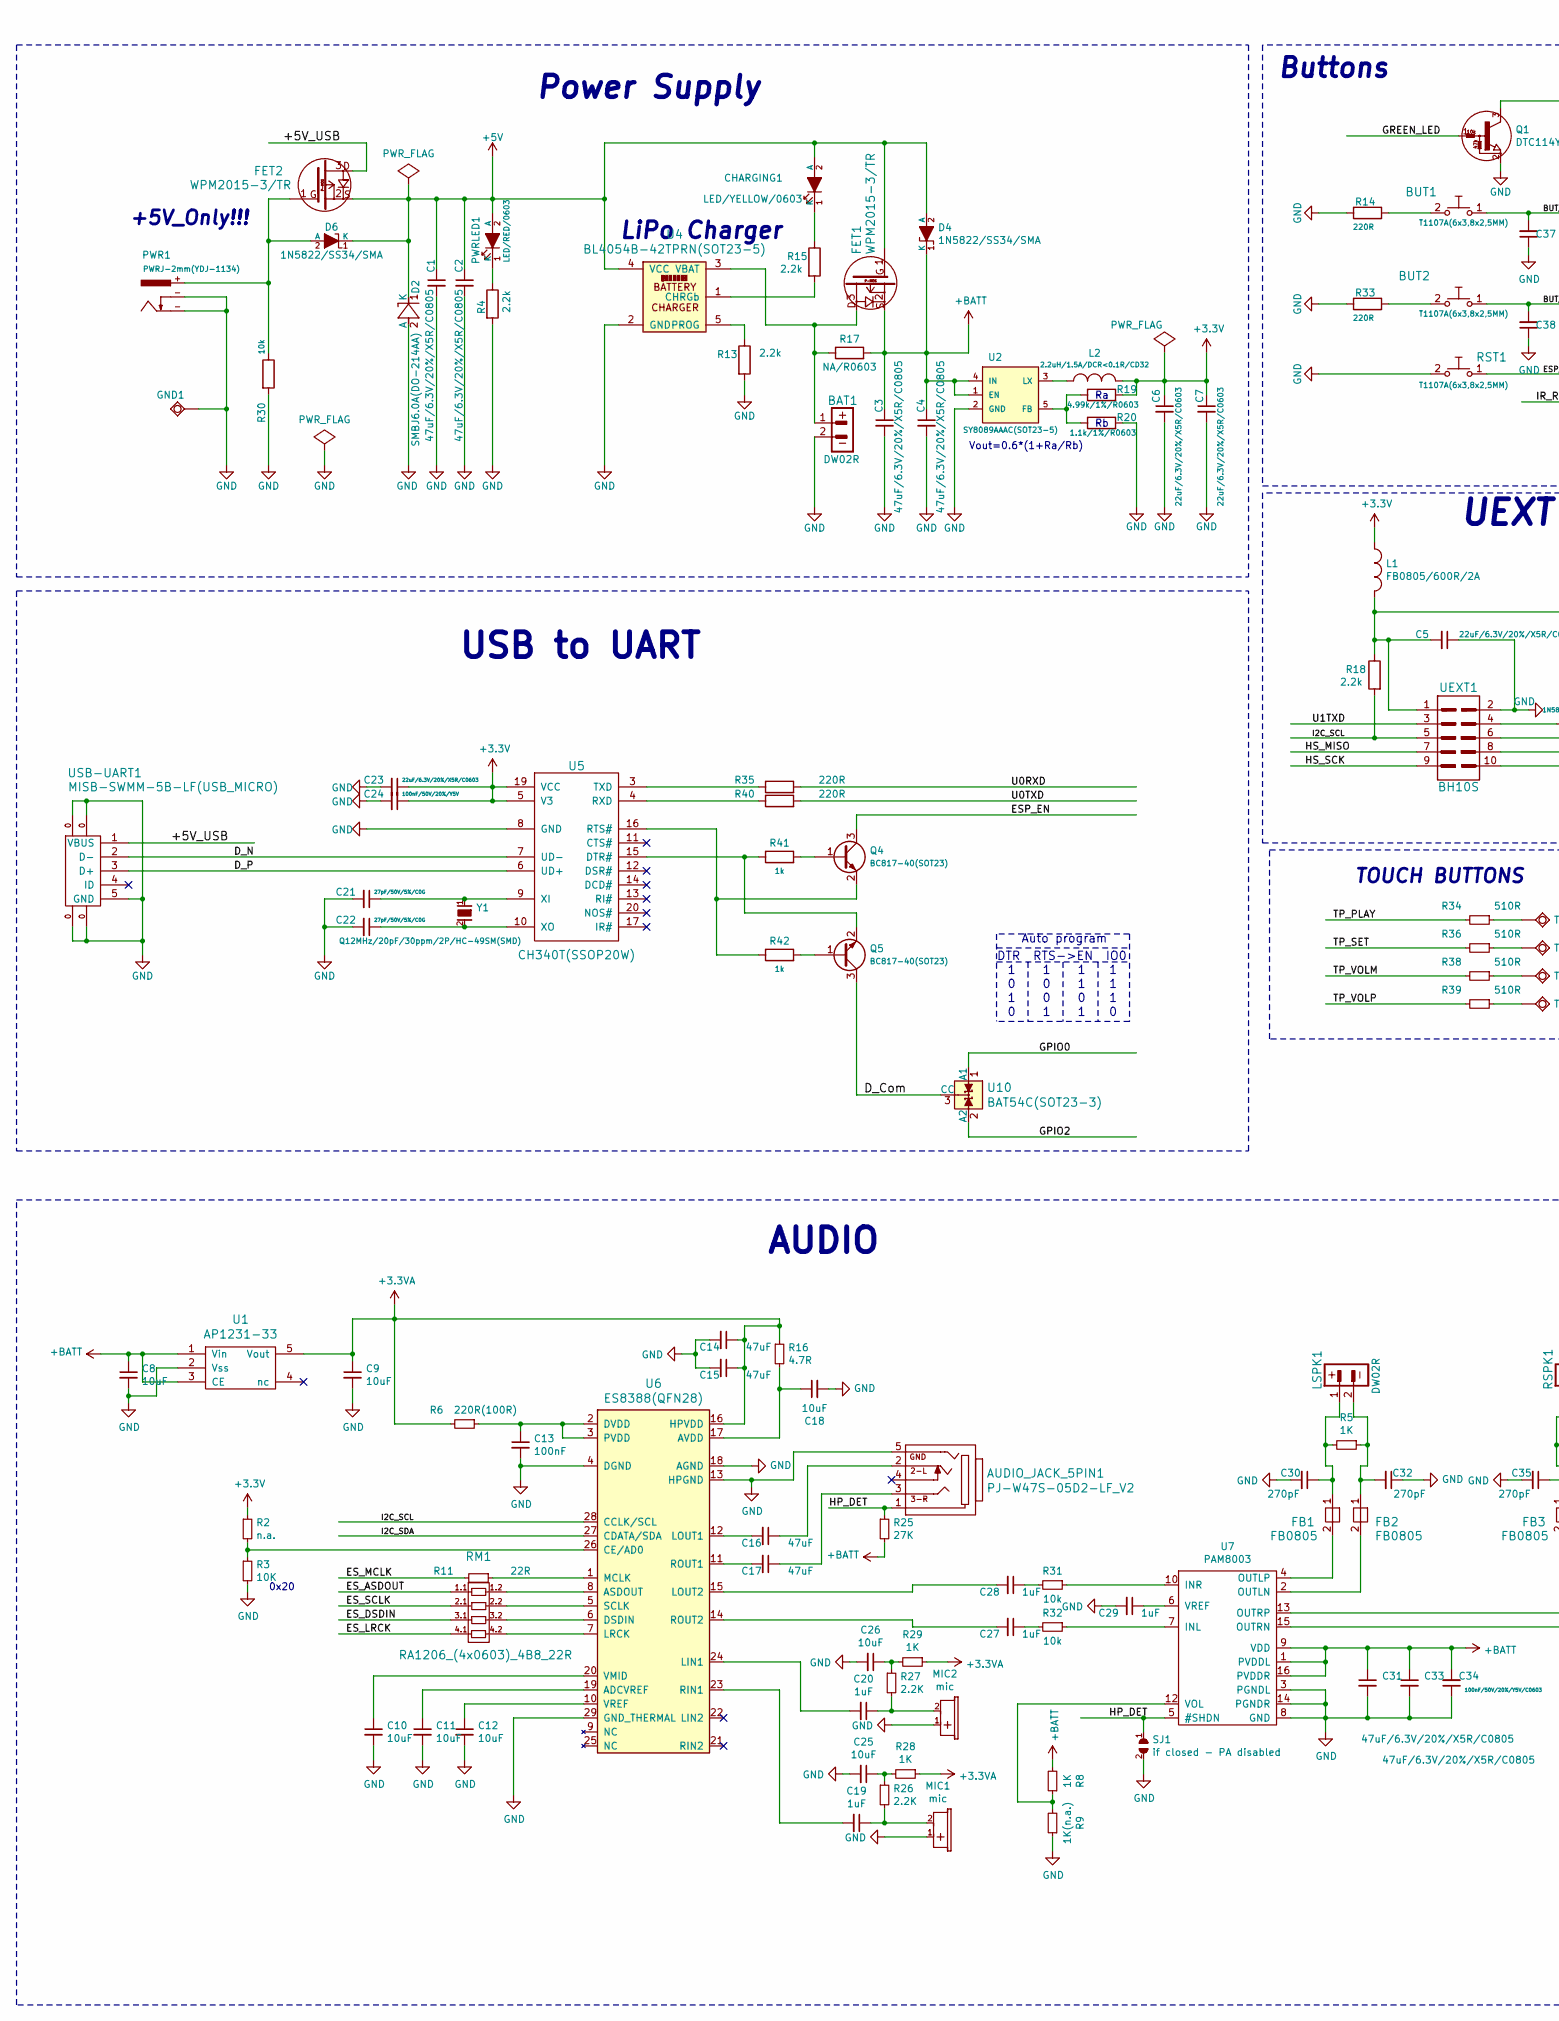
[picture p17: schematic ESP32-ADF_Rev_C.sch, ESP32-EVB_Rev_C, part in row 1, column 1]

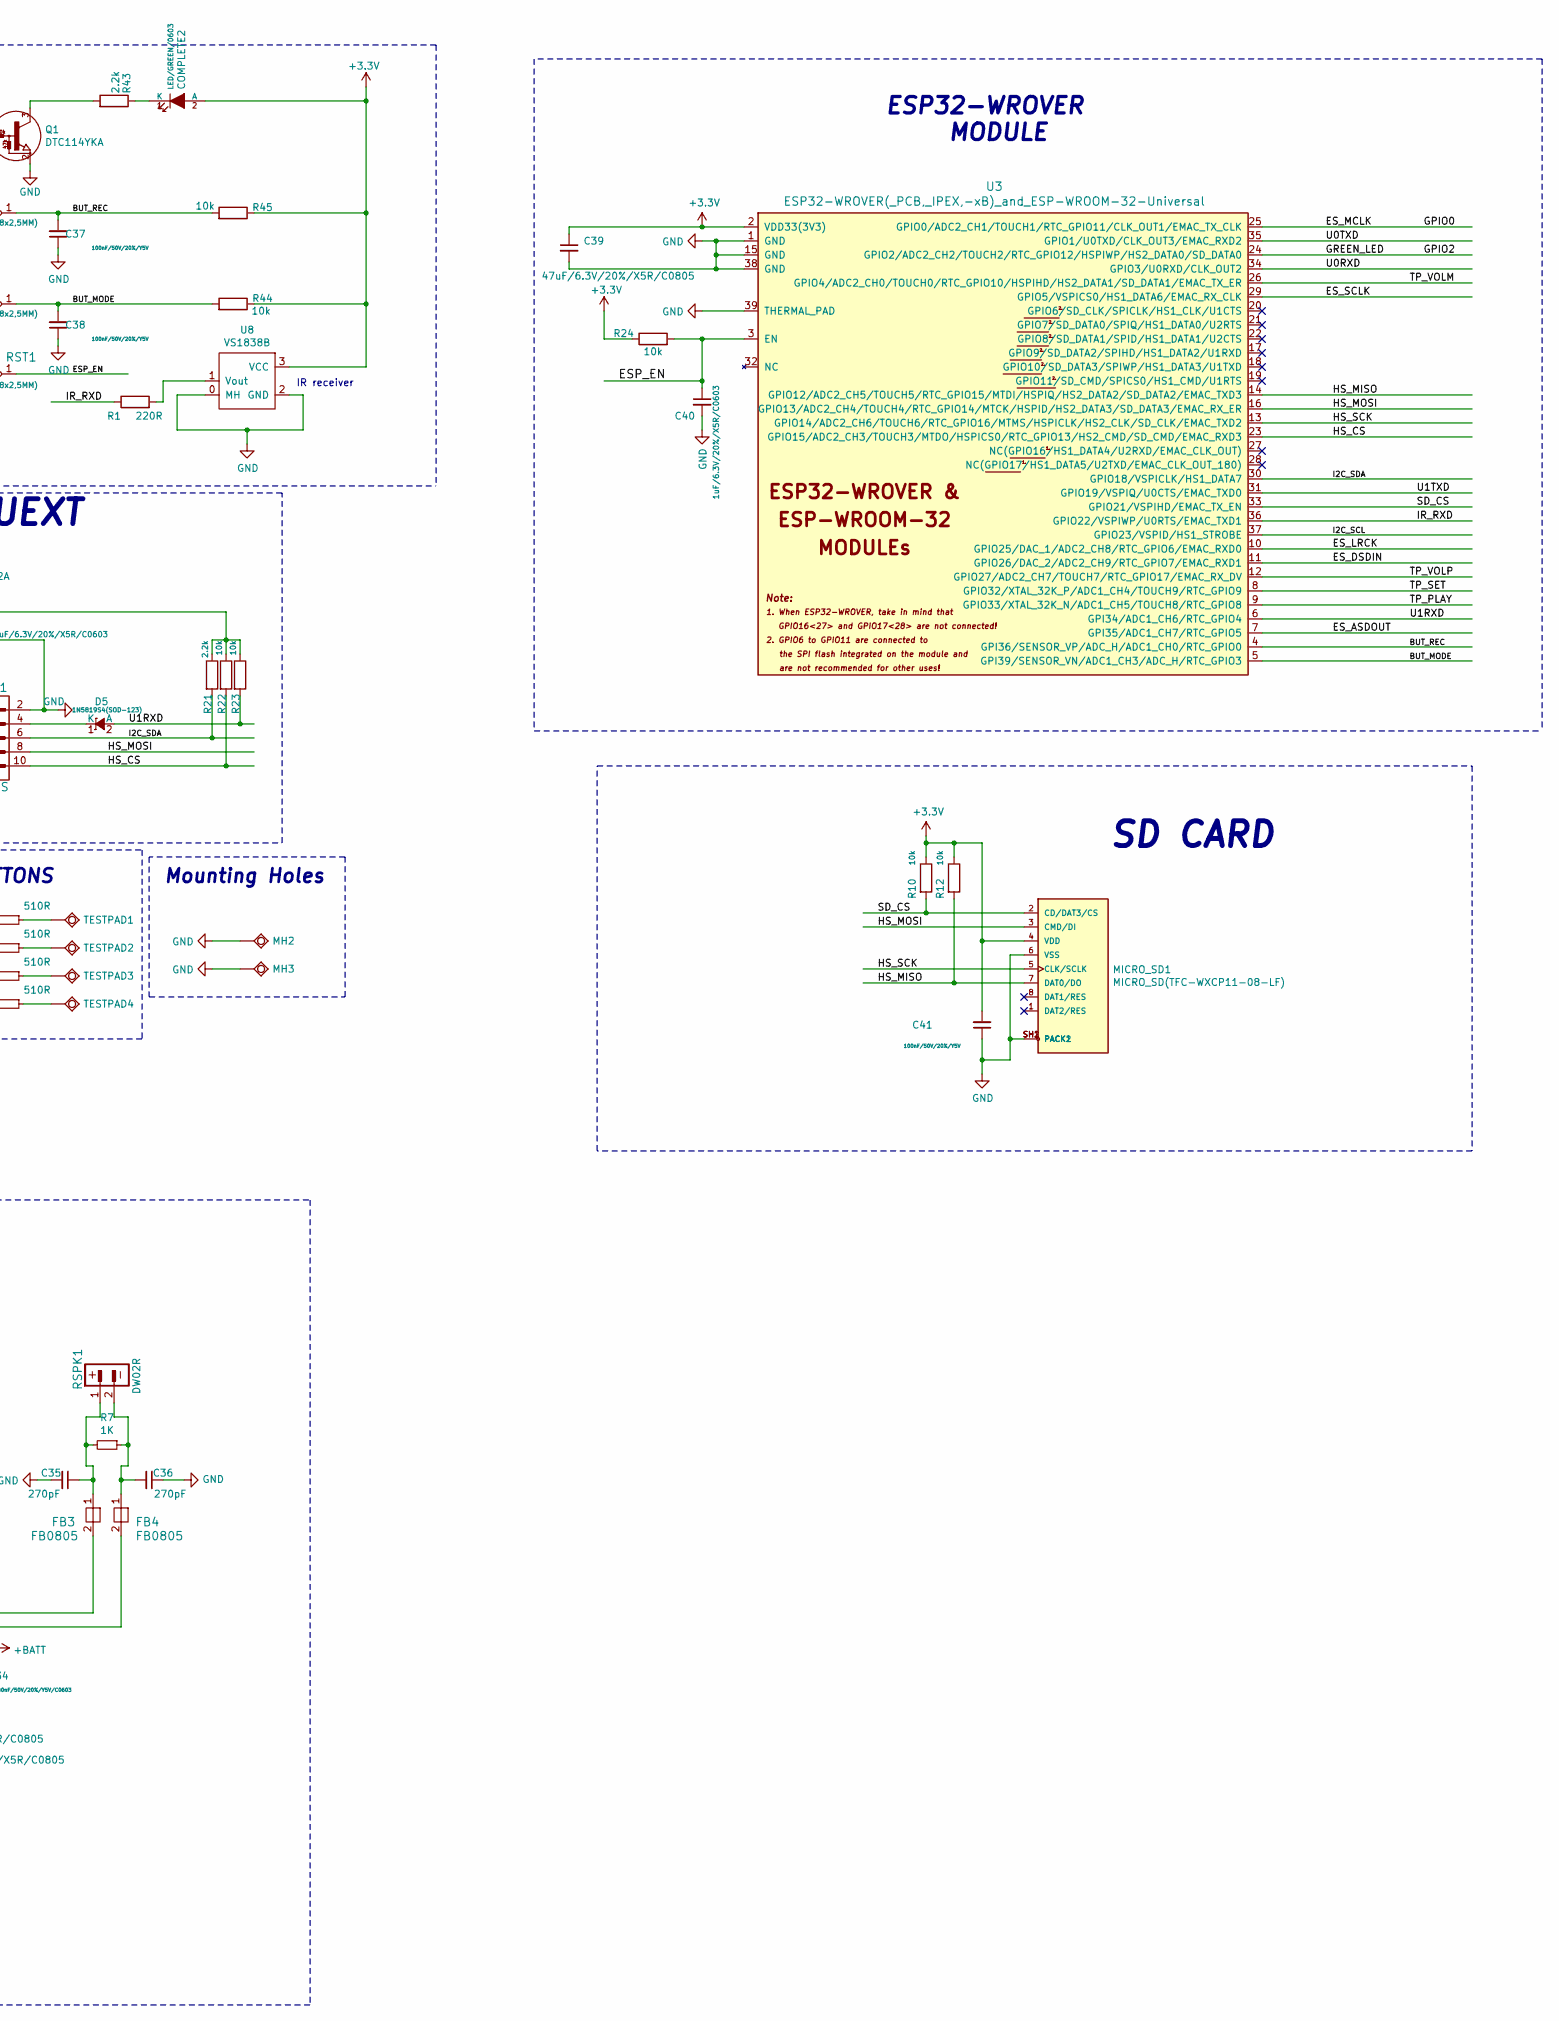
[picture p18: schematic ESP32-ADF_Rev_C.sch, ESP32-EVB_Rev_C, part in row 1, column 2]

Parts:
AUDIO_JACK_5PIN1: PJ-W47S-05D2-LF_V2; PJ-W47S-05D2-LF_5PIN_V2
BAT1: DW02R; LIPO_BAT-CON2DW02R
BUT1, BUT2: T1107A(6x3,8x2,5MM)
C1, C2, C3, C4, C31, C33, C39: 47uF/6.3V/20%/X5R/C0805; C_0805_5MIL_DWS
C5, C6, C7, C23: 22uF/6.3V/20%/X5R/C0603; C_0603_5MIL_DWS
C8, C9, C10, C11, C12, C18, C25, C26: 10uF; C_0603_5MIL_DWS
C13: 100nF; C_0603_5MIL_DWS
C14, C15, C16, C17: 47uF; C_0805_5MIL_DWS
C19, C20, C27, C28, C29: 1uF; C_0603_5MIL_DWS
C21, C22: 27pF/50V/5%/C0G; C_0603_5MIL_DWS
C24: 100nF/50V/20%/Y5V; C_0603_5MIL_DWS
C30, C32, C35, C36: 270pF; C_0402_5MIL_DWS
C34: 100nF/50V/20%/Y5V/C0603; C_0402_5MIL_DWS
C37, C38, C41: 100nF/50V/20%/Y5V; C_0402_5MIL_DWS
C40: 1uF/6.3V/20%/X5R/C0603; C_0603_5MIL_DWS
CHARGING1: LED/YELLOW/0603; LED_0603_KA
COMPLETE2: LED/GREEN/0603; LED_0603_KA
D2: SMBJ6.0A(DO-214AA); DO214AA_1(K)-2(A)
D4, D6: 1N5822/SS34/SMA; SMA-KA
D5: 1N5819S4(SOD-123); SOD-123_1C-2A_KA
FB1, FB2, FB3, FB4: FB0805; L_0805_5MIL_DWS
FET1, FET2: WPM2015-3/TR; SOT23
GND1: TESTPAD; TESTPAD_40-ROUND
L1: FB0805/600R/2A; L_0805_5MIL_DWS
L2: 2.2uH/1.5A/DCR<0.1R/CD32; CD32
LSPK1: DW02R; LIPO_BAT-CON2DW02R
MH2, MH3: Mounting_hole_Shield_3.3mm
MIC1, MIC2: mic; MIC
MICRO_SD1: MICRO_SD(TFC-WXCP11-08-LF); TFC-WXCP11-08-LF
PWR1: PWRJ-2mm(YDJ-1134); PWRJ-2mm(YDJ-1136)
PWRLED1: LED/RED/0603; LED_0603_KA
Q1: DTC114YKA; SOT23
Q4, Q5: BC817-40(SOT23); SOT23
R1, R14, R33, R35, R40: 220R; R_0402_5MIL_DWS
R2: n.a.; R_0402_5MIL_DWS
R3: 10K; R_0402_5MIL_DWS
R4, R13, R15, R18, R21, R43: 2.2k; R_0402_5MIL_DWS
R5, R7, R8, R28, R29: 1K; R_0402_5MIL_DWS
R6: 220R(100R); R_0402_5MIL_DWS
R9: 1K(n.a.); R_0402_5MIL_DWS
R10, R12, R22, R23, R24, R30, R31, R32, R44, R45: 10k; R_0402_5MIL_DWS
R11: 22R; R_0402_5MIL_DWS
R16: 4.7R; R_0402_5MIL_DWS
R17: NA/R0603; R_0402_5MIL_DWS
R19: 4.99k/1%/R0603; R_0603_5MIL_DWS
R20: 1.1k/1%/R0603; R_0603_5MIL_DWS
R25: 27K; R_0402_5MIL_DWS
R26, R27: 2.2K; R_0402_5MIL_DWS
R34, R36, R38, R39: 510R; R_0402_5MIL_DWS
R41, R42: 1k; R_0402_5MIL_DWS
RM1: RA1206_(4x0603)_4B8_22R; RA1206_(4X0603)_4B8_mine_1.1
RSPK1: DW02R; LIPO_BAT-CON2DW02R
RST1: T1107A(6x3,8x2,5MM)
SJ1: if closed - PA disabled; SJ
TESTPAD1, TESTPAD2, TESTPAD3, TESTPAD4: TESTPAD; TP_SMD_10.00x5.00mm
U1: AP1231-33; SOT-23-5
U2: SY8089AAAC(SOT23-5); SOT-23-5
U3: ESP32-WROVER(_PCB,_IPEX,-xB)_and_ESP-WROOM-32-Uni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; ESP32-WROVER_MODULE_
U4: BL4054B-42TPRN(SOT23-5); SOT-23-5
U5: CH340T(SSOP20W); SSOP-20W
U6: ES8388(QFN28); QFN28_EP(29)_4.076x4.076x0.9mm_Pitch_0.45mm
U7: PAM8003; SO-16
U8: VS1838B; RPM7236-H8
U10: BAT54C(SOT23-3); SOT23
UEXT1: BH10S; GBH-254-SMT-10_Smaller
USB-UART1: MISB-SWMM-5B-LF(USB_MICRO); USB-MICRO_MISB-SWMM-5B_LF
Y1: Q12MHz/20pF/30ppm/2P/HC-49SM(SMD); TSX-3.2x2.5mm_GND(3)

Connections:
+3.3VA: C9.1, C14.1, C15.1, R6.2, R16.1, R28.1, R29.1, U1.5 (Vout), U6.16 (HPVDD)
+3V3: C6.1, C7.1, C23.1, C24.1, C39.1, C41.2, COMPLETE2.2 (A), L1.1, L2.2, MICRO_SD1.4 (VDD), R2.1, R10.1, R12.1, R19.2, R24.1, R44.1, R45.1, U3.2 (VDD33(3V3)), U5.5 (V3), U5.19 (VCC), U8.3 (VCC)
+5V: C1.1, C2.1, CHARGING1.2 (A), D2.1 (K), D4.2 (A), D6.1 (K), FET1.1, FET2.2, PWRLED1.2 (A), U4.4 (VCC)
+BATT: C3.1, C4.1, C8.1, C31.1, C33.1, C34.2, D4.1 (K), FET1.2, R8.2, R17.2, R25.2, U1.1 (Vin), U1.3 (CE), U2.1 (EN), U2.4 (IN), U7.1 (PVDDL), U7.9 (VDD), U7.16 (PVDDR)
/+5V_USB: FET2.3, USB-UART1.1 (VBUS)
/BUT_MODE: BUT2.1, C38.2, R44.2, U3.5 (GPI39/SENSOR_VN/ADC1_CH3/ADC_H/RTC_GPIO3)
/BUT_REC: BUT1.1, C37.2, R45.2, U3.4 (GPI36/SENSOR_VP/ADC_H/ADC1_CH0/RTC_GPIO0)
/D_Com: Q5.3 (C), U10.3 (CC)
/D_N: U5.7 (UD-), USB-UART1.2 (D-)
/D_P: U5.6 (UD+), USB-UART1.3 (D+)
/ESP_EN: C40.1, Q4.3 (C), R24.2, RST1.1, U3.3 (EN)
/ES_ASDOUT: RM1.1.1, U3.7 (GPI35/ADC1_CH7/RTC_GPIO5)
/ES_DSDIN: RM1.3.1, U3.11 (GPIO26/DAC_2/ADC2_CH9/RTC_GPIO7/EMAC_RX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)
/ES_LRCK: RM1.4.1, U3.10 (GPIO25/DAC_1/ADC2_CH8/RTC_GPIO6/EMAC_RX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)
/ES_MCLK: R11.2, U3.25 (GPIO0/ADC2_CH1/TOUCH1/RTC_GPIO11/CLK_OU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), U10.1 (A1)
/ES_SCLK: RM1.2.1, U3.29 (GPIO5/VSPICS0/HS1_DATA6/EMAC_RX_CLK)
/GPIO2: Q1.1 (B), U3.24 (GPIO2/ADC2_CH2/TOUCH2/RTC_GPIO12/HSPIWP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), U10.2 (A2)
/HP_DET: AUDIO_JACK_5PIN1.1, R25.1, SJ1.1, U7.5 (#SHDN)
/HS_CS: R22.2, U3.23 (GPIO15/ADC2_CH3/TOUCH3/MTDO/HSPICS0/RTC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), UEXT1.10
/HS_MISO: MICRO_SD1.7 (DAT0/DO), R12.2, U3.14 (GPIO12/ADC2_CH5/TOUCH5/RTC_GPIO15/MTDI/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), UEXT1.7
/HS_MOSI: MICRO_SD1.3 (CMD/DI), U3.16 (GPIO13/ADC2_CH4/TOUCH4/RTC_GPIO14/MTCK/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), UEXT1.8
/HS_SCK: MICRO_SD1.5 (CLK/SCLK), U3.13 (GPIO14/ADC2_CH6/TOUCH6/RTC_GPIO16/MTMS/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), UEXT1.9
/I2C_SCL: R18.2, U3.37 (GPIO23/VSPID/HS1_STROBE), U6.28 (CCLK/SCL), UEXT1.5
/I2C_SDA: R21.2, U3.30 (GPIO18/VSPICLK/HS1_DATA7), U6.27 (CDATA/SDA), UEXT1.6
/IR_RXD: R1.1, U3.36 (GPIO22/VSPIWP/U0RTS/EMAC_TXD1)
/SD_CS: MICRO_SD1.2 (CD/DAT3/CS), R10.2, U3.33 (GPIO21/VSPIHD/EMAC_TX_EN)
/TP_PLAY: R34.2, U3.9 (GPIO33/XTAL_32K_N/ADC1_CH5/TOUCH8/RTC_G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)
/TP_SET: R36.2, U3.8 (GPIO32/XTAL_32K_P/ADC1_CH4/TOUCH9/RTC_G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)
/TP_VOLM: R38.2, U3.26 (GPIO4/ADC2_CH0/TOUCH0/RTC_GPIO10/HSPIHD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)
/TP_VOLP: R39.2, U3.12 (GPIO27/ADC2_CH7/TOUCH7/RTC_GPIO17/EMAC_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)
/U0RXD: R35.2, U3.34 (GPIO3/U0RXD/CLK_OUT2)
/U0TXD: R40.2, U3.35 (GPIO1/U0TXD/CLK_OUT3/EMAC_RXD2)
/U1RXD: D5.2 (A), R23.2, U3.6 (GPI34/ADC1_CH6/RTC_GPIO4)
/U1TXD: U3.31 (GPIO19/VSPIQ/U0CTS/EMAC_TXD0), UEXT1.3
GND: AUDIO_JACK_5PIN1.5, BAT1.2, C1.2, C2.2, C3.2, C4.2, C5.1, C6.2, C7.2, C8.2, C9.2, C10.2, C11.2, C12.2, C13.2, C14.2, C15.2, C18.2, C21.2, C22.2, C23.2, C24.2, C25.2, C26.2, C29.2, C30.2, C31.2, C32.1, C33.2, C34.1, C35.2, C36.1, C37.1, C38.1, C39.2, C40.2, C41.1, D2.2 (A), GND1.1, MH2.GND1, MH3.GND1, MIC1.1 (PLUS), MIC2.1 (PLUS), MICRO_SD1.6 (VSS), MICRO_SD1.SH1 (PACK1), MICRO_SD1.SH2 (PACK2), PWR1.-, Q1.2 (E), R3.2, R4.2, R9.1, R13.2, R14.2, R20.2, R30.2, R33.2, RST1.2, SJ1.2, U1.2 (Vss), U2.2 (GND), U3.1 (GND), U3.15 (GND), U3.38 (GND), U3.39 (THERMAL_PAD), U4.2 (GND), U5.8 (GND), U6.4 (DGND), U6.13 (HPGND), U6.18 (AGND), U6.29 (GND_THERMAL), U7.3 (PGNDL), U7.8 (GND), U7.14 (PGNDR), U8.0 (MH), U8.2 (GND), UEXT1.2, USB-UART1.0, USB-UART1.5 (GND); also elsewhere on the board
unnamed: AUDIO_JACK_5PIN1.2, C16.1
unnamed: AUDIO_JACK_5PIN1.3, C17.1
unnamed: BAT1.1, FET1.3, R17.1, U4.3 (VBAT)
unnamed: BUT1.2, R14.1
unnamed: BUT2.2, R33.1
unnamed: C5.2, L1.2, R18.1, R21.1, R22.1, R23.1, UEXT1.1
unnamed: C10.1, U6.20 (VMID)
unnamed: C11.1, U6.19 (ADCVREF)
unnamed: C12.1, U6.10 (VREF)
unnamed: C13.1, R6.1, U6.2 (DVDD), U6.3 (PVDD)
unnamed: C16.2, U6.12 (LOUT1)
unnamed: C17.2, U6.11 (ROUT1)
unnamed: C18.1, R16.2, U6.17 (AVDD)
unnamed: C19.1, MIC1.2 (MINUS), R26.2
unnamed: C19.2, U6.23 (RIN1)
unnamed: C20.1, MIC2.2 (MINUS), R27.2
unnamed: C20.2, U6.24 (LIN1)
unnamed: C21.1, U5.9 (XI), Y1.1
unnamed: C22.1, U5.10 (XO), Y1.2
unnamed: C25.1, R26.1, R28.2
unnamed: C26.1, R27.1, R29.2
unnamed: C27.1, R31.2
unnamed: C27.2, U6.14 (ROUT2)
unnamed: C28.1, R32.2
unnamed: C28.2, U6.15 (LOUT2)
unnamed: C29.1, U7.6 (VREF)
unnamed: C30.1, FB1.1, LSPK1.1, R5.2
unnamed: C32.2, FB2.1, LSPK1.2, R5.1
unnamed: C35.1, FB3.1, R7.2, RSPK1.1
unnamed: C36.2, FB4.1, R7.1, RSPK1.2
unnamed: CHARGING1.1 (K), R15.1
unnamed: COMPLETE2.1 (K), R43.1
unnamed: D5.1 (K), UEXT1.4
unnamed: D6.2 (A), FET2.1, PWR1.+, R30.1
unnamed: FB1.2, U7.4 (OUTLP)
unnamed: FB2.2, U7.2 (OUTLN)
unnamed: FB3.2, U7.13 (OUTRP)
unnamed: FB4.2, U7.15 (OUTRN)
unnamed: L2.1, U2.3 (LX)
unnamed: PWRLED1.1 (K), R4.1
unnamed: Q1.3 (C), R43.2
unnamed: Q4.1 (B), R41.2
unnamed: Q4.2 (E), R42.1, U5.16 (RTS#)
unnamed: Q5.1 (B), R42.2
unnamed: Q5.2 (E), R41.1, U5.15 (DTR#)
unnamed: R1.2, U8.1 (Vout)
unnamed: R2.2, R3.1, U6.26 (CE/AD0)
unnamed: R8.1, R9.2, U7.12 (VOL)
unnamed: R11.1, U6.1 (MCLK)
unnamed: R13.1, U4.5 (PROG)
unnamed: R15.2, U4.1 (CHRGb)
unnamed: R19.1, R20.1, U2.5 (FB)
unnamed: R31.1, U7.7 (INL)
unnamed: R32.1, U7.10 (INR)
unnamed: R34.1, TESTPAD1.1
unnamed: R35.1, U5.3 (TXD)
unnamed: R36.1, TESTPAD2.1
unnamed: R38.1, TESTPAD3.1
unnamed: R39.1, TESTPAD4.1
unnamed: R40.1, U5.4 (RXD)
unnamed: RM1.1.2, U6.8 (ASDOUT)
unnamed: RM1.2.2, U6.5 (SCLK)
unnamed: RM1.3.2, U6.6 (DSDIN)
unnamed: RM1.4.2, U6.7 (LRCK)

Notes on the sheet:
Vout=0.6*(1+Ra/Rb)
Power Supply
Buttons
UEXT
ESP32-WROVER MODULE
Mounting Holes
LiPo Charger
+5V_Only!!!
Auto program
DTR RTS->EN IO0
USB to UART
0x20
AUDIO
TOUCH BUTTONS
IR receiver
SD CARD

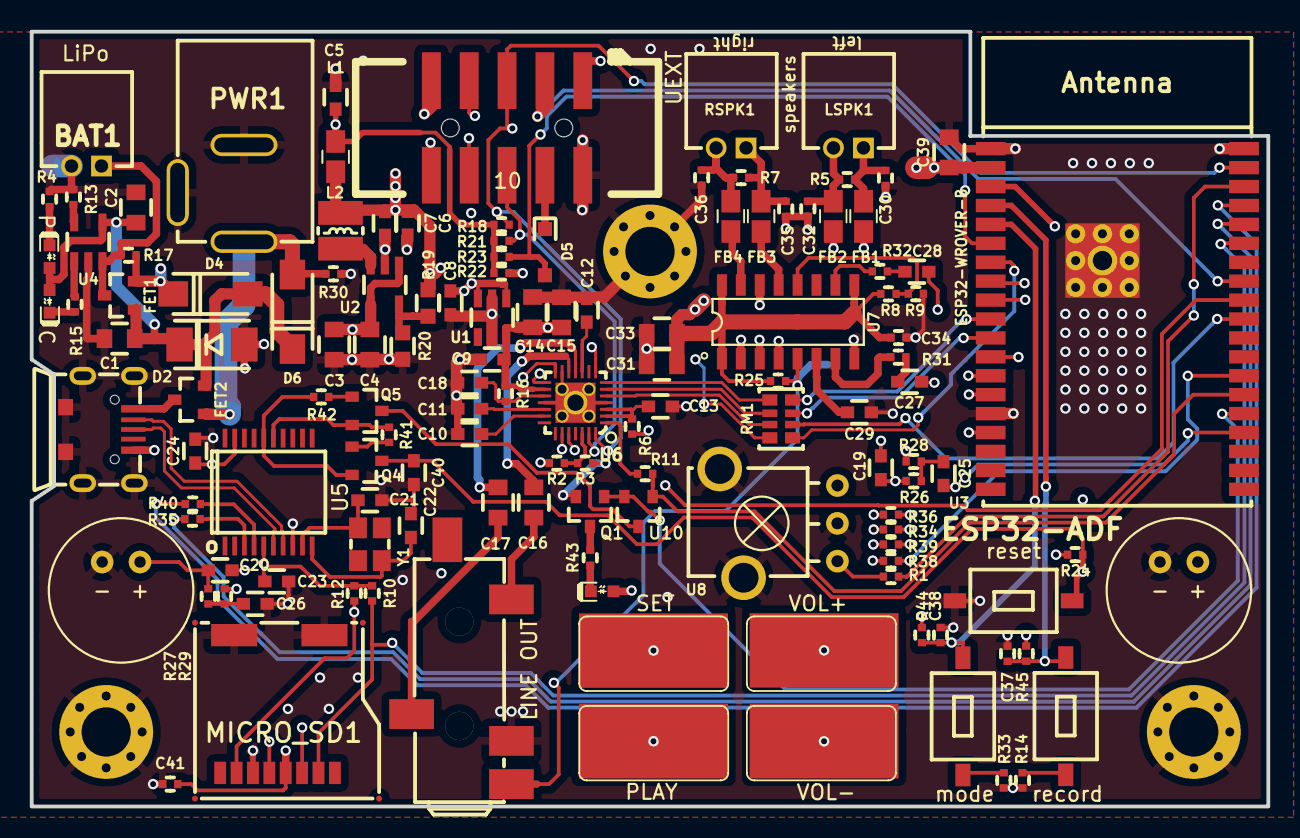
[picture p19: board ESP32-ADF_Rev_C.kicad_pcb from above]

Board: 4 copper layers, 83.0 x 52.0 mm, 135 parts (1 on the bottom side), 99 nets.

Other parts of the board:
MH3#2: Mounting_hole_Shield_3.3mm

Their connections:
GND: MH3#2.GND1; also elsewhere on the board

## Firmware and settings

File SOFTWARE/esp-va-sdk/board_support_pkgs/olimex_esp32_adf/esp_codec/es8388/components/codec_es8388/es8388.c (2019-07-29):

/*
*
* Copyright 2015-2016 Espressif Systems (Shanghai) PTE LTD
*
* Licensed under the Apache License, Version 2.0 (the "License");
* you may not use this file except in compliance with the License.
* You may obtain a copy of the License at
*
*     http://www.apache.org/licenses/LICENSE-2.0
*
* Unless required by applicable law or agreed to in writing, software
* distributed under the License is distributed on an "AS IS" BASIS,
* WITHOUT WARRANTIES OR CONDITIONS OF ANY KIND, either express or implied.
* See the License for the specific language governing permissions and
* limitations under the License.
*
*/

/*  ---------------------------------------------------------------------------------------
*   |                                                                                       |
*   |   The file includes functions and variables to configure ES8388.                      |
*   |                                                                                       |
*   ----------------------------------------------------------------------------------------
*/
#include <string.h>
#include "esp_log.h"
#include "driver/i2c.h"
#include "es8388.h"
#include <audio_board.h>

#define ES_TAG "CODEC_ES8388"

#define ES8388_DISABLE_MUTE 0x00   //disable mute
#define ES8388_ENABLE_MUTE  0x01   //enable  mute

#define ES8388_DEFAULT_VOL 45

#define ES8388_I2C_MASTER_SPEED 100000  //set master clk speed to 100k

#define ES_ASSERT(a, format, b, ...) \
    if ((a) != 0) { \
        ESP_LOGE(ES_TAG, format, ##__VA_ARGS__); \
        return b;\
    }

#define LOG_8388(fmt, ...)   ESP_LOGW(ES_TAG, fmt, ##__VA_ARGS__)

uint8_t curr_vol = 0;

/**
 * @brief Initialization function for i2c
 */
static esp_err_t audio_codec_i2c_init(int i2c_master_port)
{
    int res;
    i2c_config_t pf_i2c_pin = {0};
    
    res = audio_board_i2c_pin_config(i2c_master_port, &pf_i2c_pin);

    pf_i2c_pin.mode = I2C_MODE_MASTER;  
    pf_i2c_pin.master.clk_speed = ES8388_I2C_MASTER_SPEED;
    
    res |= i2c_param_config(i2c_master_port, &pf_i2c_pin);
    res |= i2c_driver_install(i2c_master_port, pf_i2c_pin.mode, 0, 0, 0);
    return res;
}

/**
 * @brief Write ES8388 register
 *
 * @param slave_add : slave address
 * @param reg_add    : register address
 * @param data      : data to write
 *
 * @return
 *     - (-1)  Error
 *     - (0)   Success
 */
static esp_err_t es8388_write_reg(uint8_t slave_add, uint8_t reg_add, uint8_t data)
{
    int res = 0;
    i2c_cmd_handle_t cmd = i2c_cmd_link_create();
    res |= i2c_master_start(cmd);
    res |= i2c_master_write_byte(cmd, slave_add, 1 /*ACK_CHECK_EN*/);
    res |= i2c_master_write_byte(cmd, reg_add, 1 /*ACK_CHECK_EN*/);
    res |= i2c_master_write_byte(cmd, data, 1 /*ACK_CHECK_EN*/);
    res |= i2c_master_stop(cmd);
    res |= i2c_master_cmd_begin(0, cmd, 1000 / portTICK_RATE_MS);
    i2c_cmd_link_delete(cmd);
    ES_ASSERT(res, "es8388_write_reg error", -1);
    return res;
}

/**
 * @brief Read ES8388 register
 *
 * @param reg_add    : register address
 *
 * @return
 *     - (-1)     Error
 *     - (0)      Success
 */
static esp_err_t es8388_read_reg(uint8_t reg_add, uint8_t *p_data)
{
    uint8_t data;
    esp_err_t res;
    i2c_cmd_handle_t cmd = i2c_cmd_link_create();

    res  = i2c_master_start(cmd);
    res |= i2c_master_write_byte(cmd, ES8388_ADDR, 1 /*ACK_CHECK_EN*/);
    res |= i2c_master_write_byte(cmd, reg_add, 1 /*ACK_CHECK_EN*/);
    res |= i2c_master_stop(cmd);
    res |= i2c_master_cmd_begin(0, cmd, 1000 / portTICK_RATE_MS);
    i2c_cmd_link_delete(cmd);

    cmd = i2c_cmd_link_create();
    res |= i2c_master_start(cmd);
    res |= i2c_master_write_byte(cmd, ES8388_ADDR | 0x01, 1 /*ACK_CHECK_EN*/);
    res |= i2c_master_read_byte(cmd, &data, 0x01/*NACK_VAL*/);
    res |= i2c_master_stop(cmd);
    res |= i2c_master_cmd_begin(0, cmd, 1000 / portTICK_RATE_MS);
    i2c_cmd_link_delete(cmd);

    ES_ASSERT(res, "es8388_read_reg error", -1);
    *p_data = data;
    return res;
}

/**
 * @brief Configure ES8388 ADC and DAC volume. Basicly you can consider this as ADC and DAC gain
 *
 * @param mode:             set ADC or DAC or all
 * @param volume:           -96 ~ 0              for example es8388_set_adc_dac_volume(ES8388_MODULE_ADC, 30, 6); means set ADC volume -30.5db
 * @param dot:              whether include 0.5. for example es8388_set_adc_dac_volume(ES8388_MODULE_ADC, 30, 4); means set ADC volume -30db
 *
 * @return
 *     - (-1) Parameter error
 *     - (0)   Success
 */
static esp_err_t es8388_set_adc_dac_volume(media_hal_codec_mode_t mode, float volume)
{
    esp_err_t res = 0;
    uint8_t vol;
    if ( volume < -96 || volume > 0 ) {
        LOG_8388("Warning: volume < -96! or > 0!\n");
        if (volume < -96)
            volume = -96;
        else
            volume = 0;
    }
    vol = (uint8_t) ((-1) * (volume * 2));
    
    if (mode == MEDIA_HAL_CODEC_MODE_ENCODE || mode == MEDIA_HAL_CODEC_MODE_BOTH) {
        res  = es8388_write_reg(ES8388_ADDR, ES8388_ADCCONTROL8, vol);
        res |= es8388_write_reg(ES8388_ADDR, ES8388_ADCCONTROL9, vol);  //ADC Right Volume=0db
    }
    if (mode == MEDIA_HAL_CODEC_MODE_DECODE || mode == MEDIA_HAL_CODEC_MODE_BOTH) {
        res  = es8388_write_reg(ES8388_ADDR, ES8388_DACCONTROL5, vol);
        res |= es8388_write_reg(ES8388_ADDR, ES8388_DACCONTROL4, vol);
    }
    return res;
}
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

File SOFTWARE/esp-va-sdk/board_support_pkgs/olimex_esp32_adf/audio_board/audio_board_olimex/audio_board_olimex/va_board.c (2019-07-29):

/*
*
* Copyright 2015-2018 Espressif Systems (Shanghai) PTE LTD
*
* Licensed under the Apache License, Version 2.0 (the "License");
* you may not use this file except in compliance with the License.
* You may obtain a copy of the License at
*
*     http://www.apache.org/licenses/LICENSE-2.0
*
* Unless required by applicable law or agreed to in writing, software
* distributed under the License is distributed on an "AS IS" BASIS,
* WITHOUT WARRANTIES OR CONDITIONS OF ANY KIND, either express or implied.
* See the License for the specific language governing permissions and
* limitations under the License.
*
*/

#include <string.h>
#include <esp_log.h>
#include <audio_board.h>
#include <led_olimex.h>
#include <va_board.h>

#define VA_TAG "AUDIO_BOARD"

#define VA_ASSERT(a, format, b, ...) \
    if ((a) == NULL) { \
        ESP_LOGE(PLAT_TAG, format, ##__VA_ARGS__); \
        return b;\
    }

#define I2S_PORT_NUM I2S_NUM_0

bool ab_but_mute = false;

int va_board_init()
{
    int ret;
    i2s_config_t i2s_cfg = {};
    audio_board_i2s_init_default(&i2s_cfg);
    ret = i2s_driver_install(I2S_PORT_NUM, &i2s_cfg, 0, NULL);
    if (ret != ESP_OK) {
        ESP_LOGE(VA_TAG, "Error installing i2s driver for stream");
    } else {
        i2s_pin_config_t ab_i2s_pin = {0};
        audio_board_i2s_pin_config(I2S_PORT_NUM, &ab_i2s_pin);
        i2s_set_pin(I2S_PORT_NUM, &ab_i2s_pin);
    }
    ret = i2s_zero_dma_buffer(I2S_PORT_NUM);
    return ret;
}



int but_cb_reg_handlr(int ui_but_evt)
{
    return 1;
}

esp_err_t va_board_button_init()
{
    button_cfg_t *ab_button_conf = NULL;
    ab_button_conf = (button_cfg_t *)calloc(1, sizeof(button_cfg_t));
    ab_button_conf->is_gpio = true;
    ab_button_conf->va_button_gpio_num[VA_BUTTON_TAP_TO_TALK] = 36;
    ab_button_conf->va_button_gpio_num[VA_BUTTON_VOLUME_UP] = -1;
    ab_button_conf->va_button_gpio_num[VA_BUTTON_VOLUME_DOWN] = -1;
    ab_button_conf->va_button_gpio_num[VA_BUTTON_MIC_MUTE] = 39;
    ab_button_conf->va_button_gpio_num[VA_BUTTON_FACTORY_RST] = -1;
    ab_button_conf->va_button_gpio_num[VA_BUTTON_CUSTOM_1] = -1;
    ab_button_conf->va_button_gpio_num[VA_BUTTON_CUSTOM_2] = -1;
    va_button_init(ab_button_conf, but_cb_reg_handlr);
//    ab_button_gpio_init();
    return ESP_OK;
}

extern esp_err_t ledc_lyrat_init();

esp_err_t va_board_led_init()
{
    va_led_config_t *ab_led_conf = NULL;
    led_lyrat_pattern_init(&ab_led_conf);
    ledc_lyrat_init();
    va_led_init((va_led_config_t *)ab_led_conf);
    return ESP_OK;
}

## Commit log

2019-07-18 initial upload
    [DO-214AA_SMB.step, DO-214AC_SMA.step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]
2019-07-18 add pdf schematic
2019-07-29 add software demo
    [partitions_internet_radio.csv]
2019-07-29 Google Voice assistant, Google Dialogflow, Amazon Alexa
    [partitions.csv, partitions_4mb_flash.csv, partitions_mkspiffs.csv]
2020-11-23 Update
    Revision C files
    [5040771891.stp, DO-214AA_SMB.step, DO-214AC_SMA.step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]
